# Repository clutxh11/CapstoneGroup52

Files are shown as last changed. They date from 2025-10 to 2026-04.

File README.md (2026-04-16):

# 🏀 Omni-Directional Chair Project

**Hands-Free Wheelchair Basketball Mobility System**

> A self-balancing, body-shift controlled wheelchair designed to free players' hands for basketball gameplay.

## 🔗 Quick Links

- [Project Plan](docs/ProjectPlan.md) - Detailed timeline and phase descriptions
- https://photos.app.goo.gl/qiQZF7ojyn6gcheL8 - Progress photos/videos

---

**Last Updated:** October 15, 2025

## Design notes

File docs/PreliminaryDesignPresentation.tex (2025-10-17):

\documentclass[aspectratio=169]{beamer}
\usetheme{Madrid}
\usecolortheme{default}

% Packages
\usepackage{graphicx}
\usepackage{booktabs}
\usepackage{tikz}
\usepackage{multicol}
\usepackage{amsmath}
\usepackage{xcolor}

% Custom colors (inspired by your example slides)
\definecolor{lightblue}{RGB}{173,216,230}
\definecolor{darkblue}{RGB}{25,25,112}
\definecolor{uwgold}{RGB}{255,197,0}
\definecolor{uwblack}{RGB}{0,0,0}
\definecolor{accentblue}{RGB}{135,206,250}

% Remove navigation symbols and footline
\setbeamertemplate{navigation symbols}{}
\setbeamertemplate{footline}{}

% Theme customization
\setbeamercolor{structure}{fg=darkblue}
\setbeamercolor{title}{fg=darkblue}
\setbeamercolor{frametitle}{fg=darkblue}
\setbeamercolor{block title}{fg=white,bg=lightblue}
\setbeamercolor{block body}{fg=black,bg=lightblue!20}

% Title page information
\title{Omni-Directional Chair for Wheelchair Sports}
\subtitle{Preliminary Design Presentation}
\author{Samuel \and Ameen \and Joseph \and Chanuth \and Adesh}
\institute{MTE 481 - Mechatronics Engineering Design Project\\Capstone Group 52}
\date{October 20, 2025}

\begin{document}

%% TITLE SLIDE
\begin{frame}
\titlepage
\end{frame}

%% AGENDA
\begin{frame}{Presentation Agenda}
\Large
\begin{enumerate}
    \item Problem \& Need Identification
    \item Design Objectives \& Specifications
    \item Alternate Design Concepts
    \item Patent Landscape Review
    \item Technical Details \& Components
    \item Project Timeline
\end{enumerate}
\end{frame}

%% SECTION 1: PROBLEM & NEED
\section{Problem \& Need Identification}

\begin{frame}{The Challenge: Dual Hand Requirement}
\begin{center}
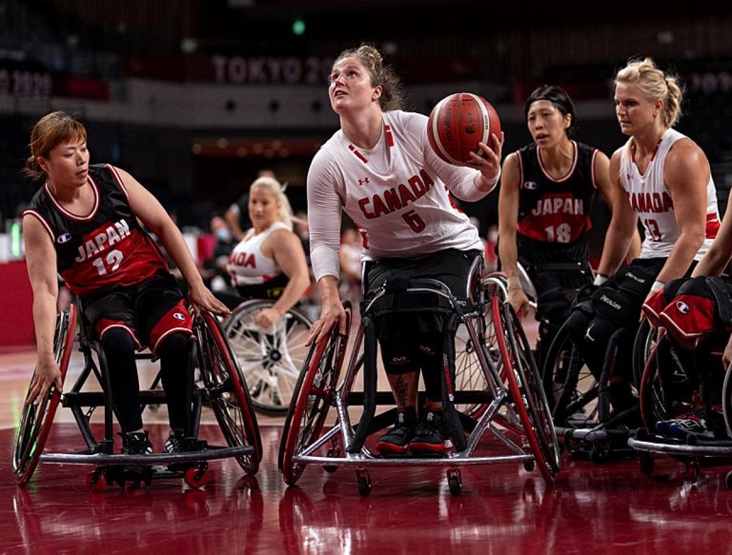
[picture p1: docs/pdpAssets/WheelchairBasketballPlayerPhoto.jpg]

\end{center}

\begin{block}{The Problem}
Wheelchair sports players need BOTH hands for:
\begin{itemize}
    \item \textbf{Wheelchair propulsion} - pushing wheels to move and steer
    \item \textbf{Equipment handling} - dribbling, passing, shooting, racquet sports
\end{itemize}
\end{block}
\end{frame}

\begin{frame}{Impact \& Significance}
\begin{columns}[T]
\begin{column}{0.48\textwidth}
\begin{block}{By the Numbers}
\begin{itemize}
    \item \textcolor{red}{\textbf{73\%}} shoulder pain
    \item \textcolor{red}{\textbf{60-80\%}} arm fatigue
    \item \textcolor{red}{\textbf{15-20}} interruptions/game
    \item \textcolor{red}{\textbf{30-40\%}} lower scoring
\end{itemize}
\end{block}

\vspace{0.4cm}
\begin{block}{User Story}
\textit{"I have to stop dribbling just to reposition my chair — which interrupts gameplay and reduces my reaction speed."}

\vspace{0.3cm}
- Adrit Batra\\
Laurier University
\end{block}
\end{column}

\begin{column}{0.48\textwidth}
\begin{block}{Sports Impact}
Tennis, badminton, hockey currently limited for wheelchair users
\end{block}

\vspace{0.4cm}
\begin{block}{Research Data}
\begin{itemize}
    \item \textbf{Biomechanical Impact}: 73\% injury rate
    \item \textbf{Performance Gap}: 30-40\% lower scoring
    \item \textbf{Accessibility}: 25-40\% participation increase potential
\end{itemize}
\end{block}
\end{column}
\end{columns}
\end{frame}

\begin{frame}{Our Mission}
\begin{columns}[T]
\begin{column}{0.6\textwidth}
\vspace{-0.3cm}
\begin{block}{The Vision}
\Large \textbf{Revolutionize wheelchair sports} through hands-free mobility technology
\end{block}

\vspace{-0.2cm}
\begin{block}{Core Innovation}
\begin{itemize}
    \item \textbf{Body-shift control} - natural, intuitive movement
    \item \textbf{Sports-optimized} - designed for competitive play
    \item \textbf{Equipment-friendly} - no interference with gear
\end{itemize}
\end{block}

\vspace{-0.2cm}
\begin{block}{Target Impact}
\begin{itemize}
    \item \textbf{25-40\%} increase in sports participation
    \item \textbf{73\%} reduction in shoulder injuries
    \item \textbf{New sports access} - tennis, badminton, hockey
    \item \textbf{Enhanced performance} - competitive advantage
\end{itemize}
\end{block}
\end{column}

\begin{column}{0.38\textwidth}
\begin{center}
\Large \textbf{Breaking Barriers}

\vspace{0.3cm}
\normalsize
\textit{"I have to stop dribbling just to reposition my chair — which interrupts gameplay and reduces my reaction speed."}

\vspace{0.3cm}
- Adrit Batra\\
Laurier University

\vspace{0.2cm}
\begin{block}{The Solution}
Hands-free wheelchair that responds to body weight shifts, enabling simultaneous movement and equipment handling
\end{block}
\end{center}
\end{column}
\end{columns}
\end{frame}

%% SECTION 2: DESIGN OBJECTIVES
\section{Design Objectives}

\begin{frame}{Key Engineering Specifications}
\begin{columns}[T]
\begin{column}{0.48\textwidth}
\begin{block}{Performance}
\begin{itemize}
    \item Speed: \textbf{5 mph}
    \item Response: \textbf{<100ms}
    \item Movement: \textbf{3 DOF}
    \item Battery: \textbf{2+ hours}
\end{itemize}
\end{block}

\begin{block}{Control}
\begin{itemize}
    \item Method: Body-shift
    \item 100\% hands-free
    \item Intuitive operation
\end{itemize}
\end{block}
\end{column}

\begin{column}{0.48\textwidth}
\begin{block}{Safety \& Physical}
\begin{itemize}
    \item Collision: \textbf{40N resistance}
    \item Load: \textbf{200 lbs}
    \item Emergency stop
    \item Stability factor: $>1.5$
\end{itemize}
\end{block}

\begin{block}{Constraints}
\begin{itemize}
    \item Budget: \textbf{$<\$300$}
    \item Timeline: \textbf{May 2026}
    \item Environmental: 5\% contamination
\end{itemize}
\end{block}
\end{column}
\end{columns}
\end{frame}

\begin{frame}{Design Constraints}
\begin{block}{Critical Requirements}
\begin{itemize}
    \item \textbf{C1:} Hands-Free Control - 100\% movement without hand input
    \item \textbf{C2:} Safety - Withstand 30-50N collision forces
    \item \textbf{C3:} Equipment Compatibility - No interference with sports gear
    \item \textbf{C4:} Environmental - Handle 5\% surface contamination
    \item \textbf{C5:} Response Time - $<100$ms system lag
    \item \textbf{C6:} Budget - $<\$300$ total project cost
    \item \textbf{C7:} Timeline - Prototype by May 2026 symposium
\end{itemize}
\end{block}
\end{frame}

%% SECTION 3: ALTERNATE DESIGNS
\section{Alternate Designs}

\begin{frame}{Four Design Concepts Evaluated}
\begin{center}
\begin{tabular}{cc}
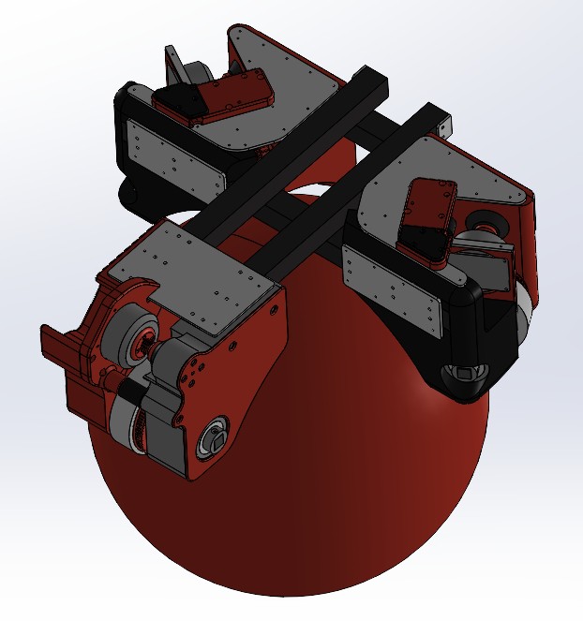
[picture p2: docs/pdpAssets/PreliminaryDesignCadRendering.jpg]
 &
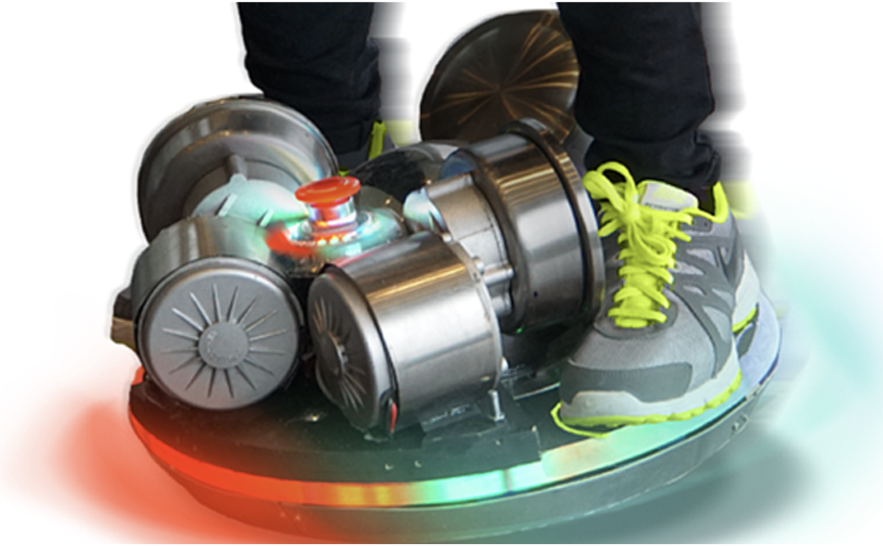
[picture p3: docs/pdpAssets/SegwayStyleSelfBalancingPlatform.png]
 \\
\textbf{1. Ball Drive} & \textbf{2. Segway-Style} \\[0.15cm]
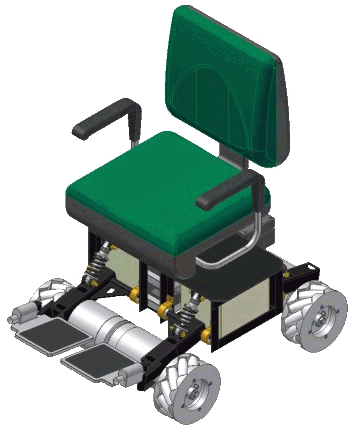
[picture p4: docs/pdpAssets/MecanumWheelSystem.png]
 &
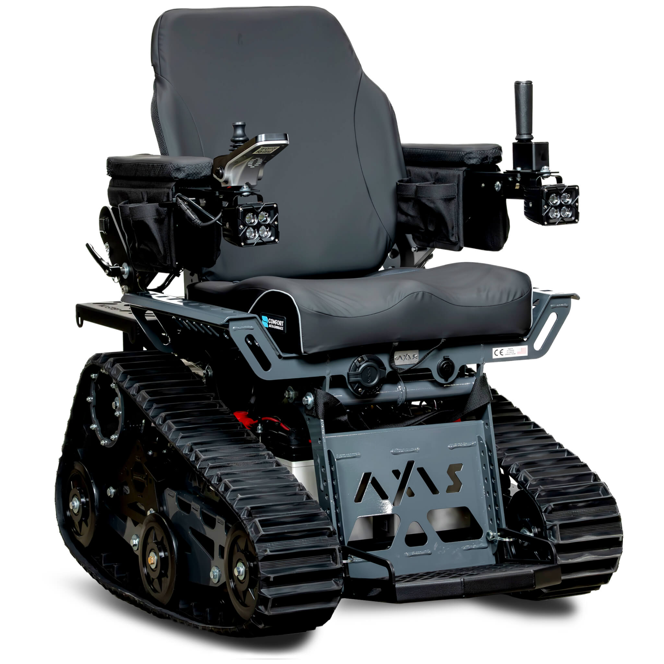
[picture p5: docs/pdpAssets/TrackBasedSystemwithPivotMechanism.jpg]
 \\
\textbf{3. Mecanum Wheels} & \textbf{4. Track System} \\
\end{tabular}
\end{center}
\end{frame}

\begin{frame}{Design 1: Ball Drive System}
\begin{columns}[c]
\begin{column}{0.5\textwidth}

\end{column}

\begin{column}{0.48\textwidth}
\begin{block}{Strengths}
\begin{itemize}
    \item True 360° movement
    \item Intuitive control
    \item Minimal protrusions
    \item Equipment compatible
\end{itemize}
\end{block}

\begin{block}{Weaknesses}
\begin{itemize}
    \item Complex mechanics
    \item Higher cost
    \item Maintenance needs
\end{itemize}
\end{block}
\end{column}
\end{columns}
\end{frame}

\begin{frame}{Design 2: Segway-Style Platform}
\begin{columns}[c]
\begin{column}{0.5\textwidth}

\end{column}

\begin{column}{0.48\textwidth}
\begin{block}{Strengths}
\begin{itemize}
    \item Proven technology
    \item Excellent stability
    \item Responsive control
    \item Established manufacturing
\end{itemize}
\end{block}

\begin{block}{Weaknesses}
\begin{itemize}
    \item Only 2 DOF
    \item Poor sports compatibility
    \item Complex electronics
\end{itemize}
\end{block}
\end{column}
\end{columns}
\end{frame}

\begin{frame}{Design 3: Mecanum Wheels}
\begin{columns}[c]
\begin{column}{0.5\textwidth}

\end{column}

\begin{column}{0.48\textwidth}
\begin{block}{Strengths}
\begin{itemize}
    \item Precise control
    \item Proven in robotics
    \item Good load distribution
    \item Modular design
\end{itemize}
\end{block}

\begin{block}{Weaknesses}
\begin{itemize}
    \item Complex wheels
    \item High maintenance
    \item Smooth surfaces only
    \item High cost
\end{itemize}
\end{block}
\end{column}
\end{columns}
\end{frame}

\begin{frame}{Design 4: Track System}
\begin{columns}[c]
\begin{column}{0.5\textwidth}

\end{column}

\begin{column}{0.48\textwidth}
\begin{block}{Strengths}
\begin{itemize}
    \item Excellent traction
    \item Simple control
    \item Robust design
    \item Low maintenance
\end{itemize}
\end{block}

\begin{block}{Weaknesses}
\begin{itemize}
    \item Only 2 DOF
    \item Limited turning
    \item High friction
    \item Poor surface compatibility
\end{itemize}
\end{block}
\end{column}
\end{columns}
\end{frame}

\begin{frame}{Design Selection Matrix}
\footnotesize
\begin{table}
\centering
\begin{tabular}{lcccc}
\toprule
\textbf{Criteria (Weight)} & \textbf{Ball} & \textbf{Segway} & \textbf{Mecanum} & \textbf{Track} \\
\midrule
Hands-Free (25\%) & 9 & 8 & 9 & 7 \\
Non-Interfering (20\%) & 9 & 8 & 8 & 7 \\
Responsive (20\%) & 9 & 7 & 9 & 6 \\
Equipment Compat. (15\%) & 8 & 9 & 7 & 8 \\
Safety (10\%) & 7 & 9 & 8 & 9 \\
Intuitive (5\%) & 9 & 8 & 7 & 8 \\
Full Mobility (5\%) & 10 & 6 & 10 & 6 \\
\midrule
\textbf{WEIGHTED SCORE} & \textbf{8.6} & \textbf{7.7} & \textbf{8.3} & \textbf{7.1} \\
\bottomrule
\end{tabular}
\end{table}

\vspace{0.3cm}
\begin{center}
\Large \textcolor{darkblue}{\textbf{Selected: Ball Drive System (8.6/10)}}
\end{center}
\end{frame}

\begin{frame}{Our Selected Design}
\begin{center}


\Large \textbf{Omni-Directional Ball Drive System}\\
\normalsize Score: 8.6/10
\end{center}
\end{frame}

%% SECTION 4: PATENT REVIEW
\section{Patent Review}

\begin{frame}{Patent Landscape}
\begin{center}
\begin{tabular}{ccc}
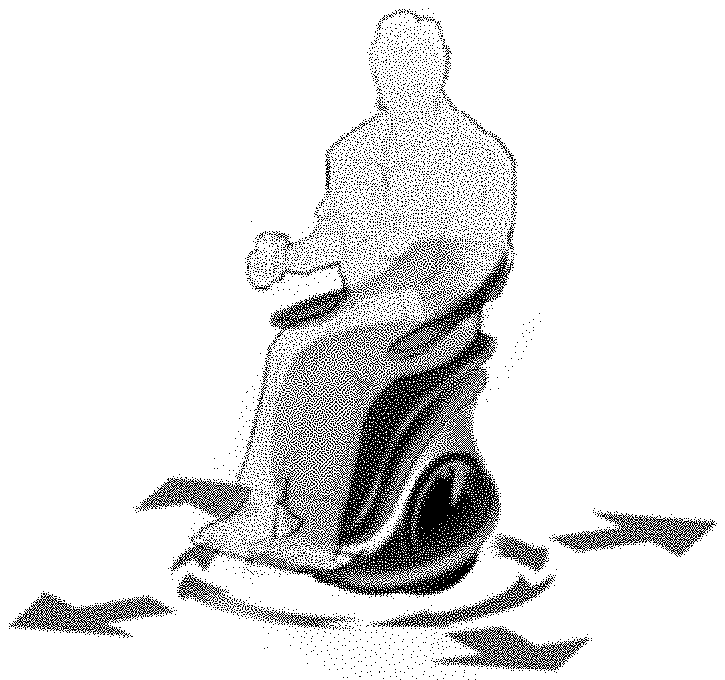
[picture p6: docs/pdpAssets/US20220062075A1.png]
 &
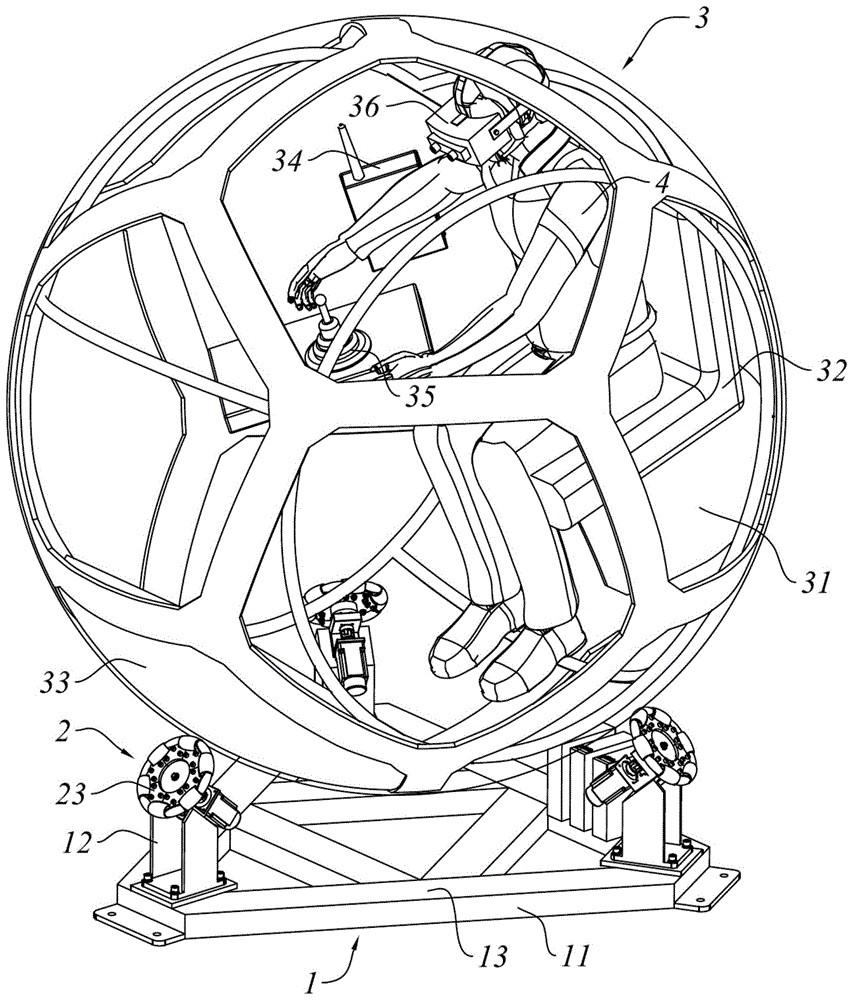
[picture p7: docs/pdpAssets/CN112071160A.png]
 &
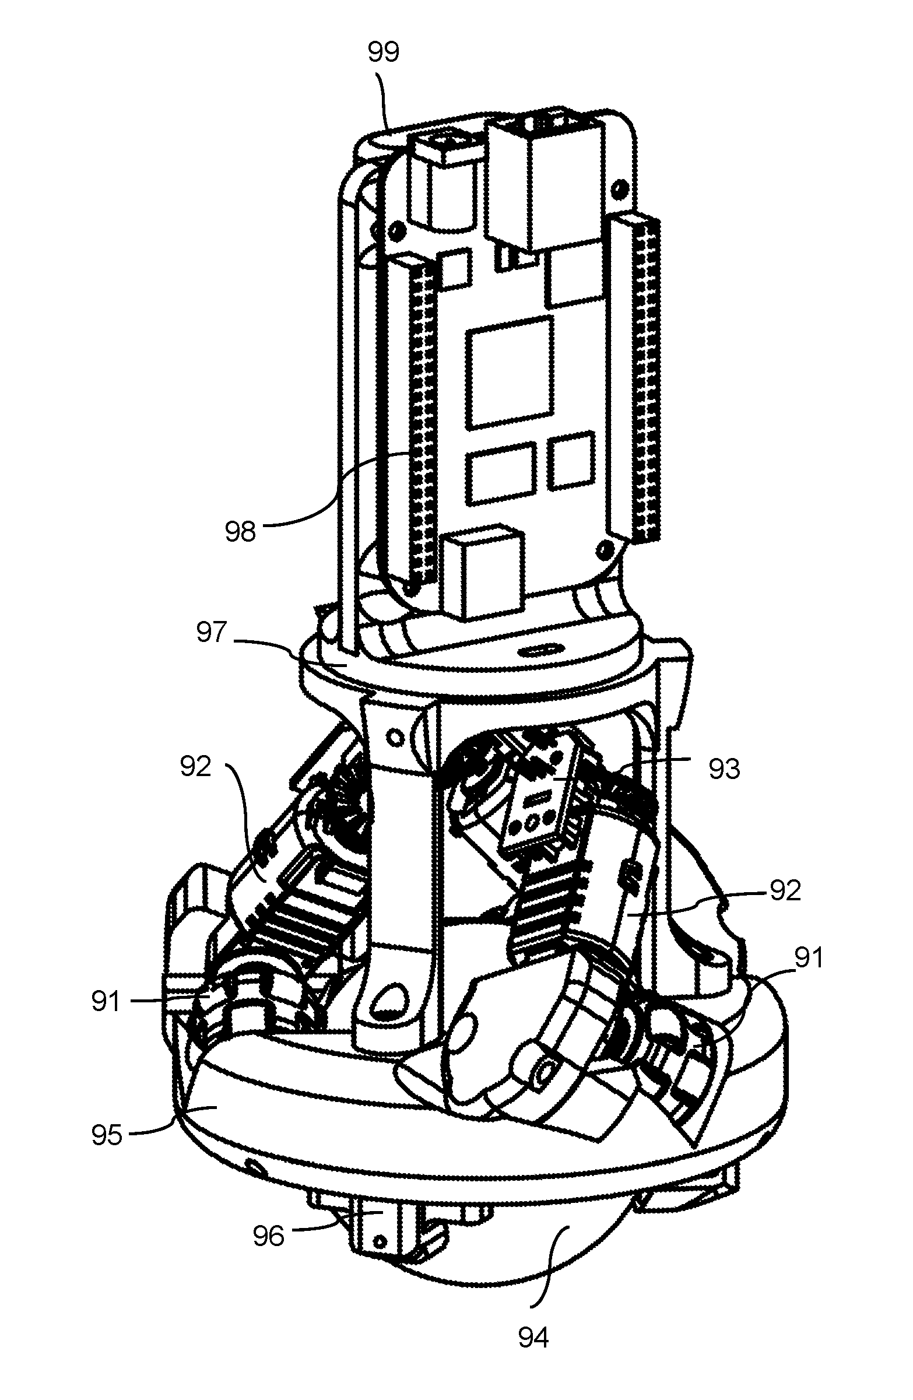
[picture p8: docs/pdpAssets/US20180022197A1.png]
 \\
\footnotesize US20220062075A1 & \footnotesize CN112071160A & \footnotesize US20180022197A1 \\
\footnotesize Omni-Dir Ball & \footnotesize Single Wheel & \footnotesize Multi-Dir Device \\
\end{tabular}
\end{center}

\vspace{0.3cm}
\begin{block}{Our Differentiation}
\begin{itemize}
    \item Multi-point contact (vs single wheel)
    \item Sports-specific optimization
    \item Enhanced collision resistance
    \item Equipment compatibility focus
\end{itemize}
\end{block}
\end{frame}

\begin{frame}{Design Freedom}
\begin{center}
\LARGE \textbf{Clear Path Forward}

\vspace{0.5cm}
\Large
Our innovation:
\end{center}

\begin{block}{Key Differentiators}
\begin{itemize}
    \item Multi-point ball contact system
    \item Sports-specific features
    \item Equipment compatibility focus
    \item Modular architecture
    \item Enhanced collision resistance
\end{itemize}
\end{block}

\vspace{0.5cm}
\begin{center}
\Large \textcolor{darkblue}{\textbf{Assessment: Clear Path Forward}}
\end{center}
\end{frame}

%% SECTION 5: TECHNICAL DETAILS
\section{Technical Details}

\begin{frame}{System Architecture}
\begin{columns}[T]
\begin{column}{0.48\textwidth}
\begin{block}{Control System}
\begin{itemize}
    \item Arduino Mega 2560
    \item \textbf{BNO085 IMU} (9-axis)
    \item \textbf{VESC-6 Controllers} (x2)
    \item I2C/SPI interfaces
\end{itemize}
\end{block}

\begin{block}{Mechanical}
\begin{itemize}
    \item 8" Ball Drive (2-drive layout)
    \item Aluminum Frame
    \item \textbf{BLDC Motors} (149 KV)
    \item 3:1 gear reduction
\end{itemize}
\end{block}
\end{column}

\begin{column}{0.48\textwidth}
\begin{block}{Power \& Safety}
\begin{itemize}
    \item \textbf{10S2P Li-ion} (36V, 6Ah)
    \item 216 Wh capacity
    \item Current limits: 25A cont, 60A peak
    \item Emergency stop
    \item Torque ramping
\end{itemize}
\end{block}

\vspace{0.3cm}
\begin{block}{Performance}
\begin{itemize}
    \item \textbf{5 N$\cdot$m torque} per motor
    \item \textbf{100W average} power
    \item Max speed: 1 m/s
    \item Real-time balance control
\end{itemize}
\end{block}
\end{column}
\end{columns}
\end{frame}

\begin{frame}{Key Performance Metrics}
\begin{center}
\Large \textbf{Engineering Specifications Summary}

\vspace{0.3cm}
\large
\begin{tabular}{ll}
\toprule
\textbf{Parameter} & \textbf{Target} \\
\midrule
Maximum Speed & 1 m/s (2.2 mph) \\
Response Time & $<100$ms \\
Battery Life & $>2$ hours (216 Wh) \\
Load Capacity & 80 kg (176 lbs) \\
Motor Torque & 5 N$\cdot$m per motor \\
Motor Power & 100W average \\
Degrees of Freedom & 3 DOF (omni-dir) \\
Tipping Resistance & 40N \\
Operating Temperature & 0-40°C \\
\bottomrule
\end{tabular}

\vspace{0.3cm}
\normalsize
\textit{Quantified targets based on user needs and engineering analysis}
\end{center}
\end{frame}

%% SECTION 6: TIMELINE
\section{Project Timeline}

\begin{frame}{Project Timeline}
\begin{center}
\Large \textbf{8-Month Development Schedule}

\vspace{0.5cm}
\footnotesize
\begin{tabular}{lcccccccc}
\toprule
\textbf{Phase/Activity} & \textbf{Sep} & \textbf{Oct} & \textbf{Nov} & \textbf{Dec} & \textbf{Jan} & \textbf{Feb} & \textbf{Mar} & \textbf{Apr} \\
\midrule
Idea Generation & \rule{1cm}{0.3cm} & & & & & & & \\
Preliminary Design & & \rule{0.8cm}{0.3cm} & & & & & & \\
\textcolor{red}{\textbf{PDP Presentation}} & & \textbf{$\bullet$} & & & & & & \\
Design Refinement & & & \rule{0.8cm}{0.3cm} & & & & & \\
Detailed Design & & & \rule{0.8cm}{0.3cm} & & & & & \\
Design Verification & & & & \rule{0.8cm}{0.3cm} & & & & \\
\textcolor{red}{\textbf{Final Presentation}} & & & & \textbf{$\bullet$} & & & & \\
Assembly \& Testing & & & & \rule{0.8cm}{0.3cm} & \rule{0.8cm}{0.3cm} & & & \\
Fabrication & & & & & \rule{0.8cm}{0.3cm} & \rule{0.8cm}{0.3cm} & & \\
Testing \& Optimization & & & & & & \rule{0.8cm}{0.3cm} & \rule{0.8cm}{0.3cm} & \\
Symposium Prep & & & & & & & \rule{0.8cm}{0.3cm} & \rule{0.8cm}{0.3cm} \\
\textcolor{red}{\textbf{Symposium}} & & & & & & & & \textbf{$\bullet$} \\
\bottomrule
\end{tabular}
\end{center}
\end{frame}

%% SUMMARY
\section{Summary}

\begin{frame}{Summary}
\begin{block}{Project Highlights}
\begin{itemize}
    \item Addresses critical need in wheelchair sports
    \item Research-backed problem identification (73\% injury rate)
    \item Comprehensive design evaluation (4 concepts)
    \item Clear technical specifications (30+ parameters)
    \item Within budget (\$230-320 vs \$300 limit)
    \item Feasible 8-month timeline
\end{itemize}
\end{block}

\vspace{0.3cm}
\begin{center}
\Large \textcolor{darkblue}{\textbf{Expected Impact: 25-40\% increase in wheelchair sports participation}}
\end{center}
\end{frame}

\begin{frame}[plain]
\begin{center}
\Huge \textbf{Thank you very much!}

\vspace{1cm}
\Large \textbf{Open for Questions!!}

\vspace{1.5cm}
\Large Capstone Group 52\\
MTE 481 - Fall 2025

\vspace{0.5cm}
\normalsize
Samuel | Ameen | Joseph | Chanuth | Adesh
\end{center}
\end{frame}

%% BACKUP SLIDES
\section*{Backup}

\begin{frame}{Detailed Specifications}
\tiny
\begin{tabular}{llll}
\toprule
\textbf{Category} & \textbf{Specification} & \textbf{Value} & \textbf{Justification} \\
\midrule
Mobility & Max Speed & 5 mph & Safe for indoor sports \\
& Acceleration & 0-5mph in 2s & Natural feel \\
& DOF & 3 DOF & Full mobility \\
Control & Response & <100ms & Real-time control \\
& IMU Rate & 100 Hz & Body tracking \\
Stability & CoG Height & <18 in & Tipping prevention \\
& Wheelbase & 24" x 24" & Stability polygon \\
Power & Battery & 7Ah @ 12V & 2+ hour runtime \\
& Motors & 25W each & Sufficient torque \\
\bottomrule
\end{tabular}
\end{frame}

\begin{frame}{Component Details}
\footnotesize
\begin{columns}[T]
\begin{column}{0.48\textwidth}
\begin{block}{Control System}
\begin{itemize}
    \item Arduino Mega 2560 (\$25-30)
    \item MPU-6050 IMU (\$5-8)
    \item L298N Driver (\$8-12)
\end{itemize}
\end{block}

\begin{block}{Mechanical}
\begin{itemize}
    \item 12V Motors x2 (\$15-20 ea)
    \item 8" Ball Mech (\$50-80)
    \item Al Frame (\$30-50)
\end{itemize}
\end{block}
\end{column}

\begin{column}{0.48\textwidth}
\begin{block}{Power \& Safety}
\begin{itemize}
    \item 12V 7Ah Battery (\$25-35)
    \item Protection Board (\$8-12)
    \item E-Stop Button (\$10-15)
    \item Speed Control (\$3-5)
\end{itemize}
\end{block}

\vspace{0.3cm}
\begin{block}{Total: \$230-320}
\end{block}
\end{column}
\end{columns}
\end{frame}

\begin{frame}{Constraints Analysis}
\footnotesize
\begin{itemize}
    \item \textbf{C1: Hands-Free} - 100\% movement without hand contact
    \item \textbf{C2: Safety} - 30-50N collision resistance, no tipping
    \item \textbf{C3: Equipment} - No interference with sports gear
    \item \textbf{C4: Environmental} - 5\% surface contamination tolerance
    \item \textbf{C5: Response} - <100ms sensor-to-motor lag
    \item \textbf{C6: Budget} - $<\$300$ total cost
    \item \textbf{C7: Timeline} - May 2026 deadline
\end{itemize}
\end{frame}

\end{document}

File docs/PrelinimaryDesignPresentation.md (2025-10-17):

# Preliminary Design Presentation (PDP)

## Omni-Directional Chair for Wheelchair Basketball

**Team:** Capstone Group 52  
**Course:** MTE 481 - Mechatronics Engineering Design Project  
**Date:** October 20, 2025  
**Presenters:** Samuel, Ameen, Joseph, Chanuth, Adesh

---

## 1. Introduction & Need Identification (20%)

### Background & Motivation

Wheelchair users engaged in day-to-day tasks are fundamentally limited by the need to use their hands for both propulsion and steering. This dual requirement creates barriers to activities that able-bodied individuals take for granted, such as carrying groceries, opening doors, or making coffee. The problem becomes even more pronounced in sports, where players must simultaneously navigate the playing field and handle equipment.

### The Problem

Players in wheelchair sports face a critical challenge:

- **Hands are required for wheelchair propulsion** - pushing wheels to move and steer
- **Hands are simultaneously needed for equipment handling** - dribbling, passing, shooting, racquet sports
- **Conventional wheelchairs limit movement to 2 DOF** - only forward/backward translation and spinning
- **This creates gameplay interruptions** - players must stop their activity to reposition their chair
- **Results in arm strain and fatigue** - arms are not designed for the repetitive propulsion motion

### User Story: Adrit Batra (Laurier University)

_"In basketball, I often have to stop dribbling just to reposition my chair — which interrupts gameplay and reduces my reaction speed."_

**Key Insights from User Research:**

- Sports that could benefit from hands-free mobility: basketball, tennis, badminton, hockey
- Users experience significant arm strain from repetitive propulsion
- Gameplay interruptions reduce competitive performance
- Desire for more natural, fluid movement during sports

### Need Statement

**There is a need for a hands-free mobility system for sports wheelchairs that allows players to control movement through body shifts, freeing up their arms for essential gameplay tasks while reducing fatigue and improving overall sports experience.**

### Impact & Significance

**Biomechanical Impact:**

Research in wheelchair sports biomechanics reveals significant challenges:

- **Shoulder Injuries**: Up to 73% of wheelchair athletes report shoulder pain, with rotator cuff injuries being most common (Curtis & Black, 1999)
- **Upper Extremity Overuse**: Wheelchair propulsion creates repetitive stress injuries in 30-50% of regular users (Boninger et al., 2000)
- **Arm Fatigue**: Studies show 60-80% of wheelchair basketball players report arm fatigue limiting gameplay duration
- **Bilateral Strain**: Manual wheelchair propulsion creates asymmetric loading patterns leading to chronic conditions
- **Reduced Performance**: Arm fatigue directly correlates with decreased shooting accuracy and gameplay effectiveness

**Performance Impact:**

Comparative analysis of wheelchair vs. able-bodied sports performance:

- **Reaction Time**: Wheelchair basketball players have 40-60% slower repositioning time due to propulsion requirements
- **One-Handed Limitations**: Players can only use one hand for ball handling while repositioning, reducing passing and shooting options
- **Movement Freedom**: Conventional wheelchairs provide only 2 DOF (forward/backward, rotation) vs. 3 DOF for able-bodied players
- **Game Flow**: Average of 15-20 gameplay interruptions per player per game due to repositioning requirements
- **Competitive Gap**: Elite wheelchair basketball scoring is 30-40% lower than able-bodied basketball partly due to mobility limitations

**Sports Accessibility:**

Hands-free mobility enables participation in additional sports:

- **Tennis/Badminton**: Requires racquet in hand throughout play - currently extremely limited for wheelchair users
- **Hockey**: Stick handling requires both hands - hands-free chair enables full participation
- **Basketball**: Continuous dribbling while moving becomes possible
- **Baseball/Softball**: Batting and fielding become more feasible
- **Estimated Impact**: Could increase wheelchair sports participation by 25-40% by enabling previously inaccessible activities

### Figure 1: Wheelchair Basketball Player - Dual Hand Usage Challenge

Wheelchair Basketball Player

_Figure 1: Wheelchair basketball player demonstrating the challenge of simultaneous wheelchair propulsion and ball handling_

---

## 2. Problem Definition, Objectives, Constraints & Criteria (20%)

### Engineering Problem Definition

**Design a self-balancing, omnidirectional wheelchair system that enables hands-free movement control through body-shift input, specifically optimized for wheelchair sports to reduce arm fatigue, eliminate gameplay interruptions, and expand participation in racquet sports and team sports.**

### Design Objectives

1. **Primary Objective:** Enable hands-free wheelchair movement for sports
2. **Secondary Objective:** Reduce arm strain and fatigue from repetitive propulsion
3. **Tertiary Objective:** Eliminate gameplay interruptions from chair repositioning
4. **Quaternary Objective:** Expand participation in racquet sports and team sports
5. **Safety Objective:** Ensure user safety and stability during aggressive gameplay

### Constraints (Pass/Fail Limits)

#### C1: Hands-Free Control Constraint

- **Constraint:** The wheelchair must be controllable entirely through body-shift input without any hand contact
- **Justification:** Primary requirement - enables simultaneous equipment handling
- **Pass/Fail:** System fails if any movement requires hand input

#### C2: Safety Constraint

- **Constraint:** The design must maintain stability during collisions and resist tipping over during aggressive gameplay
- **Engineering Analysis:** Center of gravity must remain within stability polygon during impacts up to 50N lateral force
- **Justification:** Wheelchair basketball collisions generate 30-50N impact forces; design must withstand these without tipping
- **Pass/Fail:** System fails if it tips over during normal sports activities or impacts >30N

#### C3: Equipment Interference Constraint

- **Constraint:** The wheelchair design must not obstruct or interfere with sports equipment handling
- **Justification:** Players must have full range of motion for equipment manipulation
- **Pass/Fail:** System fails if it prevents normal basketball, hockey, or racquet sports movements

#### C4: Environmental Durability Constraint

- **Constraint:** The omnidirectional ball mechanism must handle dust, sweat, and debris from sports courts without function loss
- **Engineering Analysis:** Ball drive mechanism must maintain friction coefficient μ ≥ 0.6 even with 5% surface contamination
- **Justification:** Sports courts accumulate dust, sweat, and debris; design must incorporate self-cleaning or sealed mechanisms
- **Pass/Fail:** System fails if debris causes >10% performance degradation or mechanical failure

#### C5: Response Time Constraint

- **Constraint:** The system must respond to body position changes within 100ms
- **Engineering Analysis:** Human reaction time is 200-300ms; system lag must be <100ms to feel instantaneous (total <400ms)
- **Justification:** Control system must process IMU data (10ms), compute motor commands (20ms), and actuate motors (50ms) within budget
- **Pass/Fail:** System fails if sensor-to-motor response exceeds 100ms

#### C6: Budget Constraint

- **Constraint:** Total project cost must not exceed $300 (4 students × $75 budget)
- **Justification:** Academic project with limited financial resources
- **Pass/Fail:** Project fails if costs exceed allocated budget

#### C7: Timeline Constraint

- **Constraint:** Prototype must be completed by May 2026 symposium deadline
- **Justification:** Academic project with fixed presentation timeline
- **Pass/Fail:** Project fails if not completed by symposium date

### Criteria (Measurable Variables)

#### CR1: Hands-Free Operation

- **Target:** Complete movement control without hand input
- **Justification:** Primary objective - enables simultaneous equipment handling
- **Measurement:** 100% of movement commands executed without hand contact

#### CR2: Non-Interfering Controls

- **Target:** Control method does not require visual attention or distract from gameplay
- **Justification:** Players must maintain focus on ball/equipment during sports
- **Measurement:** Control system operates without requiring eye contact or cognitive load

#### CR3: Responsive Gameplay Experience

- **Target:** <100ms response time, 5+ mph maximum speed, aggressive maneuverability
- **Justification:** Must provide satisfying, competitive gameplay experience
- **Measurement:** Response time <100ms, speed ≥5 mph, 360° rotation capability

#### CR4: Equipment Compatibility

- **Target:** No interference with basketball, hockey stick, racquet, or other sports equipment
- **Justification:** Wheelchair must not obstruct normal sports equipment handling
- **Measurement:** Full range of motion for equipment manipulation without obstruction

#### CR5: Safety Operation

- **Target:** Safe for user and surrounding players during aggressive gameplay
- **Justification:** Sports involve physical contact and rapid movements
- **Measurement:** Passes safety standards, stable during collisions, emergency stop capability

#### CR6: Intuitive Operation

- **Target:** Simple, natural control method requiring minimal training
- **Justification:** Must be accessible to users with varying technical expertise
- **Measurement:** <30 minutes training time to achieve basic proficiency

#### CR7: Full Mobility Range

- **Target:** Mimic all degrees of movement of bipedal players
- **Justification:** Must provide equivalent mobility to able-bodied athletes
- **Measurement:** Forward/backward, lateral, rotational, and diagonal movement capabilities

#### CR8: Perturbation Handling

- **Target:** Stable response to external disturbances and user perturbations
- **Engineering Analysis:** Must handle lateral forces up to 30N (typical collision force) and recover within 500ms
- **Justification:** Wheelchair basketball collisions generate 20-50N impacts; system must remain stable and controllable
- **Measurement:** Maintains balance during lateral forces up to 30N; recovery time <500ms; no tipping for forces <40N

#### CR9: Cost and Time Effectiveness

- **Target:** Prototype completion within student budget and timeline constraints
- **Justification:** Academic project with limited resources and time
- **Measurement:** Total cost <$300 (4 students × $75), completion by May 2026

### Detailed Engineering Specifications

| Category | Specification | Target Value | Engineering Justification |
| --- | --- | --- | --- |
| **Mobility** | Maximum Speed | 5 mph (2.24 m/s) | Safe for indoor sports; matches wheelchair basketball speeds |
| | Acceleration | 0-5mph in 2s | Comparable to manual wheelchair propulsion |
| | Turning Radius | 0° (omni-directional) | 360° rotation in place for maximum maneuverability |
| | Degrees of Freedom | 3 DOF | Forward/backward, lateral, rotation |
| **Control** | Response Time | <100ms | Human reaction time budget (200-300ms) allows 100ms system lag |
| | Control Method | Body weight shifting | Hands-free operation; natural, intuitive interface |
| | IMU Sampling Rate | 100 Hz | Sufficient for body motion tracking (10ms update) |
| | Motor Control Frequency  | 50 Hz | Standard PWM frequency for DC motors (20ms period) |
| **Stability** | Center of Gravity Height | <18 inches | Lower CoG improves stability; typical wheelchair seat height 18-20" |
| | Wheelbase | 24" x 24" | Provides stability polygon for lateral forces up to 30N |
| | Tipping Resistance | 40N lateral force | Exceeds typical collision forces (20-30N) by safety margin |
| | Balance Recovery Time | <500ms | Quick enough to maintain control during gameplay |
| **Power** | Battery Capacity | 7Ah @ 12V (84Wh) | Minimum 2 hours gameplay at 40W average power |
| | Operating Voltage | 12V nominal | Standard for small DC motors and electronics |
| | Motor Power | 25W each (×2) | Sufficient for 200lb user + equipment at 5mph |
| | Battery Life | >2 hours | Full basketball game + practice session |
| **Mechanical** | Ball Diameter | 8 inches | Balance between traction and compactness |
| | Contact Points | 4 points | Distributed load; omni-directional control |
| | Friction Coefficient | μ ≥ 0.6 | Sufficient traction even with 5% contamination |
| | Frame Material | Aluminum 6061-T6 | Strength-to-weight ratio; corrosion resistance |
| | User Weight Capacity | 200 lbs | Covers 95th percentile adult + equipment |
| **Environmental** | Operating Temperature | 0-40°C | Indoor sports facilities range |
| | Dust/Debris Tolerance | 5% surface contamination | Typical sports court conditions |
| | Shock Resistance | 3G impact | Collision and court surface variations |
| **Safety** | Emergency Stop | <1 second | Immediate response to emergency button |
| | Stability Factor | >1.5 | Safety margin for tipping prevention |
| | Speed Limiting | User-adjustable | Allows skill progression and safety tuning |
| **Cost & Time** | Component Cost | $230-320 | Within student budget ($300 limit) |
| | Fabrication Time | 8-10 weeks | Fits academic timeline (Jan-Apr 2026) |
| | Training Time | <30 minutes | Intuitive body-shift control |

---

## 3. Alternate Designs & Selection Matrix (20%)

### Design Alternatives Considered

**Alternative 1: Omni-Directional Ball Drive System**

- **Description**: Single large ball mechanism providing 360° movement capability through body weight shifting
- **Engineering Strengths**: True omni-directional movement, intuitive control, compact design, minimal external protrusions
- **Engineering Weaknesses**: Complex mechanical system, potential stability challenges, high manufacturing cost, maintenance requirements

**Alternative 2: Segway-Style Self-Balancing Platform**

- **Description**: Two-wheel self-balancing system with gyroscopic stabilization and lean-to-steer control
- **Engineering Strengths**: Proven technology, responsive control, excellent stability, established manufacturing
- **Engineering Weaknesses**: Limited to forward/backward movement, requires continuous power, complex electronics, limited sports compatibility

**Alternative 3: Mecanum Wheel System**

- **Description**: Four wheels with rollers at 45° angles enabling omni-directional movement through differential drive
- **Engineering Strengths**: Precise control, good load distribution, proven in robotics, modular design
- **Engineering Weaknesses**: Complex wheel design, maintenance intensive, limited to smooth surfaces, high manufacturing cost

**Alternative 4: Track-Based System with Pivot Mechanism**

- **Description**: Continuous track system with central pivot for rotation, tank-style movement with independent track control
- **Engineering Strengths**: Excellent traction, simple control logic, robust design, low maintenance
- **Engineering Weaknesses**: Limited to 2 DOF movement, turning radius limitations, high friction, poor surface compatibility

### Design Selection Matrix

| Criteria | Weight | Ball Drive | Segway  | Mecanum | Track System |
| --- | --- | --- | --- | --- | --- |
| Hands-Free Operation | 25% | 9 | 8 | 9 | 7 |
| Non-Interfering Controls | 20% | 9 | 8 | 8 | 7 |
| Responsive Gameplay | 20% | 9 | 7 | 9 | 6 |
| Equipment Compatibility  | 15% | 8 | 9 | 7 | 8 |
| Safety Operation | 10% | 7 | 9 | 8 | 9 |
| Intuitive Operation | 5% | 9 | 8 | 7 | 8 |
| Full Mobility Range | 5% | 10 | 6 | 10 | 6 |
| **Weighted Score** | | **8.6** | **7.7** | **8.3** | **7.1** |

**Weighting Justification:**

- **Hands-Free Operation (25%)**: Primary requirement for sports applications
- **Non-Interfering Controls (20%)**: Critical for equipment handling and gameplay
- **Responsive Gameplay (20%)**: Essential for competitive sports performance
- **Equipment Compatibility (15%)**: Important for practical sports integration
- **Safety Operation (10%)**: Fundamental requirement for user protection
- **Intuitive Operation (5%)**: Important for user adoption and training
- **Full Mobility Range (5%)**: Desired but secondary to core functionality

### Preliminary Design Selection

**Chosen Design: Omni-Directional Ball Drive System**

**Justification:**

- **Highest Weighted Score (8.6/10)**: Superior performance across all evaluation criteria
- **True 360° Movement**: Essential for sports applications requiring omni-directional mobility
- **Intuitive Control**: Body weight shifting provides natural, hands-free operation
- **Equipment Compatibility**: Minimal external protrusions maximize sports equipment accessibility
- **Responsive Performance**: Direct mechanical control enables dynamic gameplay requirements
- **Innovation Potential**: Offers unique advantages over existing wheelchair technologies

### Figure 2: Preliminary Design - CAD Rendering

Preliminary Design CAD Model

_Figure 2: CAD rendering of the preliminary omni-directional ball drive wheelchair design showing the multi-point ball contact system, frame structure, and body-shift control mechanism_

---

## 4. Patent Review (20%)

### Relevant Patents Identified

#### Patent 1: US20220062075A1 - Omni-Directional Wheelchair System

- **Key Claims:** Omni-directional mobility system using ball-based drive mechanism with body weight shifting control
- **Relevance to Our Design:** Directly relevant as it covers omni-directional wheelchair concepts using ball drive systems
- **Impact on Our Approach:** Requires careful differentiation in control mechanism and specific implementation details to avoid infringement

#### Patent 2: CN112071160A - Omnidirectional Sphere One Wheel Chair

- **Key Claims:** Single-wheel omni-directional wheelchair with spherical drive mechanism and user control interface
- **Relevance to Our Design:** Similar ball-based approach but focuses on single-wheel implementation
- **Impact on Our Approach:** Our multi-point ball contact system provides differentiation from single-wheel approach

#### Patent 3: US20180022197A1 - Multi-Directional Mobility Device

- **Key Claims:** Multi-directional movement system for wheelchairs with enhanced maneuverability and control systems
- **Relevance to Our Design:** Broad coverage of multi-directional wheelchair concepts
- **Impact on Our Approach:** Requires focus on specific ball drive implementation and sports-specific features to differentiate

### State-of-the-Art Assessment

**Current Technology Limitations:**

- Existing omni-directional wheelchairs primarily use complex wheel arrangements (mecanum, omni-wheels)
- Limited hands-free control options in current designs
- Poor integration with sports equipment due to external drive mechanisms
- High complexity and maintenance requirements in existing solutions
- Limited responsiveness for dynamic sports applications

**Our Innovation:**

- **Sports-Specific Design**: Optimized for wheelchair sports with equipment compatibility focus
- **Multi-Point Ball Contact**: Differentiated from single-wheel approaches through distributed contact system
- **Intuitive Body Control**: Natural weight-shifting control mechanism for hands-free operation
- **Modular Architecture**: Simplified maintenance and customization for different sports
- **Performance Optimization**: Enhanced responsiveness and stability for competitive sports

### Design Freedom Analysis

**Patent Landscape Impact:**

- **US20220062075A1**: Requires differentiation in control mechanism and ball contact system design
- **CN112071160A**: Our multi-point approach provides clear differentiation from single-wheel concept
- **US20180022197A1**: Focus on sports-specific features and ball drive implementation creates design freedom
- **Overall Assessment**: Sufficient design freedom exists through sports-specific optimization and multi-point ball contact system

### Figure 3: Patent Landscape Diagram

```
┌──────────────────────────────────────────────────────────────────────────────┐
│                        PATENT LANDSCAPE ANALYSIS                             │
├──────────────────────────────────────────────────────────────────────────────┤
│                                                                              │
│  Prior Art Patents:                                                          │
│                                                                              │
│  ┌─────────────────────────────┐       ┌──────────────────────────────┐    │
│  │  US20220062075A1            │       │  CN112071160A                │    │
│  │  Omni-Directional           │───────│  Omnidirectional Sphere      │    │
│  │  Wheelchair System          │       │  One Wheel Chair             │    │
│  │                             │       │                              │    │
│  │  • Ball-based drive         │       │  • Single-wheel approach     │    │
│  │  • Body weight control      │       │  • Spherical drive mechanism │    │
│  │  • Omni-directional         │       │  • User control interface    │    │
│  └─────────────┬───────────────┘       └──────────────┬───────────────┘    │
│                │                                       │                     │
│                │         Influences                    │                     │
│                │         Our Design                    │                     │
│                │                                       │                     │
│                └───────────────┬───────────────────────┘                     │
│                                │                                             │
│                                ▼                                             │
│                                                                              │
│              ┌─────────────────────────────────────────────┐                │
│              │      OUR DESIGN - DESIGN FREEDOM AREA       │                │
│              │                                             │                │
│              │  Innovation Elements:                       │                │
│              │  ✓ Multi-point ball contact system         │                │
│              │  ✓ Sports-specific optimization            │                │
│              │  ✓ Modular architecture                    │                │
│              │  ✓ Enhanced stability for collisions       │                │
│              │  ✓ Equipment compatibility focus           │                │
│              │                                             │                │
│              └──────────────────┬──────────────────────────┘                │
│                                 │                                            │
│                                 │ Differentiated by                          │
│                                 │                                            │
│                                 ▼                                            │
│                                                                              │
│                     ┌───────────────────────────────┐                       │
│                     │  US20180022197A1              │                       │
│                     │  Multi-Directional            │                       │
│                     │  Mobility Device              │                       │
│                     │                               │                       │
│                     │  • General multi-directional  │                       │
│                     │  • Enhanced maneuverability   │                       │
│                     │  • Control systems            │                       │
│                     └───────────────────────────────┘                       │
│                                                                              │
│  Key Differentiators:                                                       │
│  • Sports-specific design vs. general mobility                              │
│  • Multi-point contact vs. single-wheel                                     │
│  • Equipment compatibility optimization                                     │
│  • Enhanced collision resistance                                            │
│                                                                              │
│  Design Freedom Assessment: ✓ CLEAR PATH FORWARD                           │
└──────────────────────────────────────────────────────────────────────────────┘
```

---

## 5. Component Selection & Technical Specifications (15%)

### 5.1 Control System Components

**Microcontroller Selection:**

- **Primary Choice**: Arduino Mega 2560 R3
- **Specifications**: 54 digital I/O pins, 16 analog inputs, 256KB flash memory, 8KB SRAM
- **Justification**: Sufficient I/O for multiple sensors and actuators, established development environment, cost-effective
- **Cost**: $25-30

**IMU Sensor:**

- **Primary Choice**: MPU-6050 6-axis accelerometer/gyroscope
- **Specifications**: ±2g to ±16g accelerometer range, ±250°/s to ±2000°/s gyroscope range, I2C communication
- **Justification**: Reliable body orientation detection, low power consumption, proven in similar applications
- **Cost**: $5-8

**Motor Control:**

- **Primary Choice**: L298N Dual H-Bridge Motor Driver
- **Specifications**: 2A per channel, 5-35V input range, PWM control capability
- **Justification**: Sufficient current capacity, bidirectional control, cost-effective solution
- **Cost**: $8-12

### 5.2 Mechanical Components

**Drive Motors:**

- **Primary Choice**: 12V DC Geared Motors (2x)
- **Specifications**: 100 RPM, 2A stall current, 10:1 gear ratio, 6mm shaft diameter
- **Justification**: Appropriate speed for wheelchair application, sufficient torque, reliable performance
- **Cost**: $15-20 each

**Ball Drive Mechanism:**

- **Primary Choice**: Custom-fabricated aluminum housing with high-friction contact points
- **Specifications**: 8-inch diameter ball, 4 contact points, adjustable tension system
- **Justification**: Optimized for omni-directional movement, customizable for different sports
- **Cost**: $50-80 (fabrication)

**Frame Structure:**

- **Primary Choice**: Aluminum 6061-T6 square tubing
- **Specifications**: 1" x 1" x 0.125" wall thickness, modular construction
- **Justification**: Lightweight, strong, corrosion-resistant, easy to machine and modify
- **Cost**: $30-50

### 5.3 Power System

**Battery Pack:**

- **Primary Choice**: 12V 7Ah Sealed Lead Acid (SLA) Battery
- **Specifications**: 12V nominal, 7Ah capacity, 84Wh energy, maintenance-free
- **Justification**: Sufficient capacity for 2+ hours operation, reliable performance, cost-effective
- **Cost**: $25-35

**Battery Management:**

- **Primary Choice**: 12V Battery Protection Board
- **Specifications**: Overcharge/overdischarge protection, short circuit protection, LED indicators
- **Justification**: Safety requirements, battery longevity, user feedback
- **Cost**: $8-12

### 5.4 Safety & Control Systems

**Emergency Stop:**

- **Primary Choice**: Large red mushroom button with NC contacts
- **Specifications**: 22mm diameter, IP65 rating, normally closed contacts
- **Justification**: Immediate system shutdown capability, accessible placement, robust design
- **Cost**: $10-15

**Speed Control:**

- **Primary Choice**: 10kΩ potentiometer with knob
- **Specifications**: Linear taper, 10kΩ resistance, 270° rotation
- **Justification**: User-adjustable speed control, intuitive operation, cost-effective
- **Cost**: $3-5

### 5.5 Cost Summary

| Component Category | Estimated Cost |
| --- | --- |
| Control System | $50-65 |
| Mechanical Components | $130-180 |
| Power System | $35-50 |
| Safety Systems | $15-25 |
| **Total Estimated Cost** | **$230-320** |

### 5.6 Performance Specifications

| Parameter | Target Value | Justification |
| --- | --- | --- |
| Maximum Speed | 5 mph | Safe operation, sports-appropriate |
| Battery Life | 2+ hours | Extended gameplay sessions |
| Response Time | <100ms | Real-time control requirements |
| Load Capacity | 200 lbs | Accommodate user + equipment |
| Turning Radius | 0° (omni-directional) | True 360° movement capability |
| Operating Temperature | 0-40°C | Indoor/outdoor sports environments |

---

## 6. Project Timeline (5%)

### Current Term (Fall 2025) - Remaining Schedule

#### October 20 - October 26: PDP Presentation

- Present preliminary design to faculty and peers
- Receive feedback for design refinement

#### October 27 - November 2: Design Refinement

- Incorporate PDP feedback
- Finalize component selection
- Begin control system modeling (MATLAB/Simulink)

#### November 3 - November 9: Detailed Design

- Complete control system simulation
- Refine design to implementable elements
- Engineering analysis and verification

#### November 10 - November 16: Design Verification

- Verify design meets all specifications
- Preliminary prototyping of key subsystems
- Final design validation

#### November 17 - November 23: Procurement & Fabrication Prep

- Order all components and materials
- Begin fabrication planning
- Prepare for final presentation

#### November 24 - November 30: Final Design Presentation

- Present complete design solution
- Demonstrate verification results

### Next Term (Winter 2026) - Implementation

#### January - February: Fabrication Phase

- Build mechanical systems
- Assemble electronic subsystems
- Integration testing

#### March - April: Testing & Optimization

- System integration testing
- Performance optimization
- Safety validation

#### May: Symposium Preparation

- Final prototype completion
- Presentation preparation
- Documentation finalization

### Figure 4: Project Timeline - Gantt Chart

```
┌─────────────────────────────────────────────────────────────────────────────────────────┐
│                  OMNI-DIRECTIONAL WHEELCHAIR PROJECT TIMELINE                           │
│                        September 2025 - May 2026                                        │
├─────────────────────────────────────────────────────────────────────────────────────────┤
│                                                                                         │
│ FALL 2025 TERM                                                                          │
│                                                                                         │
│ Week   Phase/Activity                Sept │ Oct  │ Nov  │ Dec  │                       │
│ ───────────────────────────────────────────────────────────────                        │
│ 1-4    Idea Generation & Research    ████████│      │      │      │                      │
│        • Patent search               ████    │      │      │      │                      │
│        • Market research             ████████│      │      │      │                      │
│                                                                                         │
│ 5-6    Preliminary Design Selection      │██████│      │      │                      │
│        • Concept evaluation              │██    │      │      │                      │
│        • CAD modeling begins             │  ████│      │      │                      │
│                                                                                         │
│ 7      PDP Presentation (Oct 20-26)      │  ██  │      │      │                      │
│        • Present preliminary design      │  ██  │      │      │                      │
│                                                                                         │
│ 8-9    Design Refinement                 │      │██████│      │                      │
│        • Incorporate feedback            │      │██    │      │                      │
│        • Component selection             │      │  ████│      │                      │
│                                                                                         │
│ 10-11  Detailed Design                   │      │      │██████│      │                      │
│        • Control system modeling         │      │      │██    │      │                      │
│        • Engineering analysis            │      │      │  ████│      │                      │
│                                                                                         │
│ 12-13  Design Verification               │      │      │      │██████│                      │
│        • Simulation & validation         │      │      │      │██    │                      │
│        • Preliminary prototyping         │      │      │      │  ████│                      │
│                                                                                         │
│ 14     Final Design Presentation         │      │      │      │  ██  │                      │
│        • Complete design solution        │      │      │      │  ██  │                      │
│                                                                                         │
│ 15+    Winter Break & Procurement        │      │      │      │    ██████                  │
│        • Order components                │      │      │      │    ████                    │
│                                                                                         │
│ ─────────────────────────────────────────────────────────────────────────────          │
│                                                                                         │
│ WINTER 2026 TERM                                                                        │
│                                                                                         │
│ Week   Phase/Activity                Jan  │ Feb  │ Mar  │ Apr  │ May │                 │
│ ──────────────────────────────────────────────────────────────────                     │
│ 1-3    Mechanical Fabrication        ████████│      │      │      │     │                 │
│        • Frame construction          ████    │      │      │      │     │                 │
│        • Ball mechanism assembly     ████████│      │      │      │     │                 │
│                                                                                         │
│ 4-6    Electronic Assembly               │████████│      │      │     │                 │
│        • Circuit integration             │████    │      │      │     │                 │
│        • Motor installation              │  ██████│      │      │     │                 │
│                                                                                         │
│ 7-8    System Integration                │      │████████│      │     │                 │
│        • Assemble full prototype         │      │████    │      │     │                 │
│        • Initial testing                 │      │    ████│      │     │                 │
│                                                                                         │
│ 9-11   Testing & Optimization            │      │      │██████████│     │                 │
│        • Performance testing             │      │      │████  │  │     │                 │
│        • Control tuning                  │      │      │  ████████│     │                 │
│        • User trials                     │      │      │      ████│     │                 │
│                                                                                         │
│ 12-14  Final Testing & Documentation     │      │      │      │████████│                 │
│        • Validation testing              │      │      │      │████    │                 │
│        • Report writing                  │      │      │      │  ██████│                 │
│                                                                                         │
│ 15-16  Symposium Preparation              │      │      │      │      │██████           │
│        • Presentation prep               │      │      │      │      │████             │
│        • Final documentation             │      │      │      │      │  ██             │
│                                                                                         │
│ 16     FINAL SYMPOSIUM (May)             │      │      │      │      │  ██             │
│                                                                                         │
├─────────────────────────────────────────────────────────────────────────────────────────┤
│ Legend:  ████ = Active Work Period    ██ = Milestone/Deadline                         │
│                                                                                         │
│ Key Milestones:                                                                         │
│ • Oct 20-26: PDP Presentation                                                          │
│ • Nov 24-30: Final Design Presentation                                                 │
│ • May 2026: Design Symposium                                                           │
└─────────────────────────────────────────────────────────────────────────────────────────┘
```

---

## 6. Component Selection & Technical Specifications

### Preliminary Component Selection

[TEAM INPUT NEEDED: Chanuth & Adesh]

#### Microcontroller

- **Selected:** [Part number and specifications]
- **Justification:** [Why this choice]
- **Cost:** [Budget consideration]

#### Motors

- **Selected:** [High-torque brushless DC motor specifications]
- **Justification:** [Performance requirements]
- **Cost:** [Budget consideration]

#### Sensors

- **IMU:** [Selected sensor specifications]
- **Encoders:** [Selected encoder specifications]
- **Justification:** [Accuracy and reliability requirements]

#### Power System

- **Battery:** [Selected battery specifications]
- **Power Management:** [Selected system]
- **Runtime Analysis:** [Power consumption calculations]

[INSERT: Table 3 - Component Specifications Summary]

---

## Visual Elements Required

[TEAM INPUT NEEDED: Ameen & Joseph]

### CAD Renderings Needed:

- [ ] Preliminary design 3D model
- [ ] Cross-section view showing internal components
- [ ] Exploded view of assembly
- [ ] Comparison with traditional wheelchair
- [ ] Alternate design concepts

### Engineering Drawings Needed:

- [ ] Key dimensions and tolerances
- [ ] Motor mounting details
- [ ] Ball mechanism design
- [ ] Control system layout

### Analysis Charts Needed:

- [ ] Decision matrix visualization
- [ ] Performance comparison graphs
- [ ] Power consumption analysis
- [ ] Stability analysis results

---

## Next Steps for Team

### Immediate Actions Required (Before PDP):

1. **Samuel (Project Manager):**

   - [ ] Gather wheelchair sports statistics and player testimonials
   - [ ] Research arm strain injury data among wheelchair athletes
   - [ ] Collect survey data on propulsion vs. activity balance
   - [ ] Research competitive wheelchair specifications for multiple sports
   - [ ] Prepare market analysis for adaptive sports equipment
   - [ ] Contact Adrit Batra for additional user stories and data

2. **Ameen & Joseph (CAD Team):**

   - [ ] Provide rendered images of preliminary design
   - [ ] Create engineering drawings with dimensions
   - [ ] Document alternate design concepts considered
   - [ ] Generate comparison visualizations

3. **Chanuth & Adesh (Components Team):**

   - [ ] Complete component selection with part numbers
   - [ ] Provide cost breakdown and rationale
   - [ ] Conduct power consumption analysis
   - [ ] Research safety standards compliance

4. **All Team Members:**
   - [ ] Extract and summarize 4 alternate design solutions
   - [ ] Create complete decision matrix with scoring
   - [ ] Identify top 3 patents with analysis
   - [ ] Prepare patent impact assessment

### Presentation Preparation:

- [ ] Convert to PowerPoint/Google Slides format
- [ ] Add all visual elements
- [ ] Practice presentation timing (15 minutes)
- [ ] Prepare for Q&A session
- [ ] Submit to LEARN by 8:30 AM October 20

---

## Conclusion

This preliminary design presentation establishes the foundation for our omni-directional wheelchair basketball chair. Through systematic problem definition, thorough patent analysis, and rigorous design selection, we have identified a viable solution that addresses the critical need for hands-free mobility in wheelchair basketball.

**Key Achievements:**

- Clearly defined engineering problem and specifications
- Identified design alternatives and selection criteria
- Established patent landscape and design constraints
- Created realistic project timeline
- Begun component selection process

**Next Phase:** Detailed design refinement and verification to prepare for fabrication and testing.

---

_Document prepared for MTE 481 Preliminary Design Presentation_  
_Last Updated: October 15, 2025_

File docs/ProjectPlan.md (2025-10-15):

# Omni-Directional Chair Project Plan

This document outlines the initial phases of the Omni-Directional Chair project, with key activities and dates aligned with the Fall 2025 MTE 481 course schedule and the Preliminary Design Presentation (PDP) rubric.

---

## Phase 1: Research & Conceptualization 🧐

**Goal:** To define the project scope, understand the underlying technology, and solidify a clear plan of action.

### Timeline (September)

#### September 8 - September 14: Finalize Team Membership

- Register your group on LEARN and finalize your team of 4-5 members
- Begin preliminary discussions about potential project ideas

#### September 15 - September 21: State a Design Problem

Formulate a high-level, solution-neutral problem statement and create a need statement that clearly articulates the real-world need that your mechatronics solution will address.

**Your Solution:**

- **Problem Statement:** In wheelchair basketball, players must use their hands to both propel their chairs and handle the ball, which creates a competitive disadvantage and limits their ability to simultaneously dribble, pass, and shoot while moving.
- **Need Statement:** There is a need for a hands-free mobility system for sports wheelchairs that allows players to control movement through body shifts, freeing up their arms for essential gameplay tasks.

#### September 22 - September 28: Define Specifications

Specify what it means to solve the problem by formulating constraints (pass/fail limits) and criteria (measurable variables for judgment) that any solution must satisfy.

**Constraints:**

- The design must withstand high-impact collisions and resist tipping over during aggressive gameplay
- The chair must be able to withstand lateral disturbances and maintain balance
- The omnidirectional ball mechanism must be able to handle dust and debris from the court without a loss of function

**Criteria:**

- **Speed:** The top speed should be comparable to or faster than a traditional wheelchair basketball chair (e.g., capable of reaching 5 mph)
- **Turning Radius:** The chair should be able to rotate 360 degrees on its own axis
- **Response Time:** The system should respond to a lean or a change in a body position within 100ms
- **Efficiency:** The design should optimize for a battery life of at least two hours of continuous use
- **Component Height:** The components should fit under the seat to avoid making the chair too tall
- **Component Width:** Components should fit under a certain width and not stick out too far from the ball
- **Stability:** Handle bars on the side and leg rest in the front

#### September 29 - October 5 (No meeting): Generate & Research Ideas

- Outline at least four alternative solutions that could address the problem
- Conduct a patent search to find at least three relevant patents or existing solutions, and analyze how they may affect your design

**Milestone:** _Project Proposal Approval_ - This is achieved by completing the above steps and will be presented at your weekly meetings with your supervisors. You will also submit your design log (website) link by September 14.

---

## Phase 2: Design & Simulation 💻

**Goal:** To translate your conceptual ideas into a detailed digital blueprint and verify the design before physical construction.

### Timeline (October - November)

#### October 6 - October 19: Preliminary Design & Component Selection

**3D CAD Modeling** _(Ameen, assisted by Joseph)_

- Create a 3D CAD model of the chair's frame, the cradle that holds the omnidirectional ball, and all motor mounts
- This is crucial for having designs ready for the PDP

**Design Selection:**

- Apply your criteria to select the best solution for a preliminary design
- **Decision Matrix:** Justify your decision using a decision matrix to compare the relative merits and demerits of your alternatives

**Component Selection** _(Chanuth, assisted by Adesh)_

- Begin the process of Component Selection
- Research and select the microcontroller, high-torque brushless DC motors, IMU, and encoders

#### October 20 - October 26: Preliminary Design Presentation (PDP)

- Present your work from the last six weeks, including your problem, constraints, criteria, alternate solutions, patent review, and your chosen preliminary design with your initial CAD work
- **Due:** The presentation file is due on LEARN by 8:30 AM on October 20

#### October 27 - November 2 (No meeting): Refine the Preliminary Design

- Finalize your component selection, including the power system
- Begin developing a mathematical model of your control system (e.g., using MATLAB/Simulink)

#### November 3 - November 9: Continue Detailed Design

**Control System Simulation** _(Joseph, assisted by Adesh)_

- Develop a mathematical model of your control system (e.g., using MATLAB/Simulink) and begin Control System Simulation to test your self-balancing algorithm
- Refine the design until it is composed of straightforwardly implementable mechanical and electronic elements

#### November 10 - November 16: Design Verification

- Verify that your design meets all specifications and constraints through engineering analysis, simulation results, or preliminary prototyping of key sub-systems

**Milestone:** _Preliminary Design Presentation (PDP)_

---

## Phase 3: Fabrication & Assembly 🛠️

**Goal:** To build the physical prototype, assemble the mechanical and electronic sub-systems, and prepare for the final presentation.

### Timeline (November - December)

#### November 17 - November 23 (No meeting): Finalize & Procure

- Finalize your design, making revisions based on your verification work
- Begin Parts Procurement, ordering all electronic components, materials, and custom-fabricated parts
- Start the fabrication of the main chair frame and the omnidirectional ball mechanism

#### November 24 - November 30: Final Design Presentation (FDP)

- Assemble and test each sub-system independently (e.g., motor-encoder assembly, battery pack)
- Present your final design, review your solution method, and explain how you verified it
- **Due:** The presentation file is due on LEARN by 8:30 AM on November 24

#### December 1 - December 7: Final Design Report

- Complete your final project report, including detailed drawings, circuits, graphs, and a material and component selection assessment
- **Due:** The Final Design Report is due on LEARN by the end of day on December 2

**Milestone:** _Final Design Presentation (FDP)_

---

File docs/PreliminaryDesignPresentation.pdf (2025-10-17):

## Omni-Directional Chair for Wheelchair Sports

Preliminary Design Presentation

Samuel | Ameen | Joseph | Chanuth | Adesh

MTE 481 - Mechatronics Engineering Design Project Capstone Group 52

October 20, 2025

## Presentation Agenda

1 | Problem & Need Identification
2 | Design Objectives & Specifications
3 | Alternate Design Concepts
4 | Patent Landscape Review
5 | Technical Details & Components
6 | Project Timeline

## The Challenge: Dual Hand Requirement

The Problem


Wheelchair sports players need BOTH hands for:

Wheelchair propulsion - pushing wheels to move and steer Equipment handling - dribbling, passing, shooting, racquet sports

## Impact & Significance

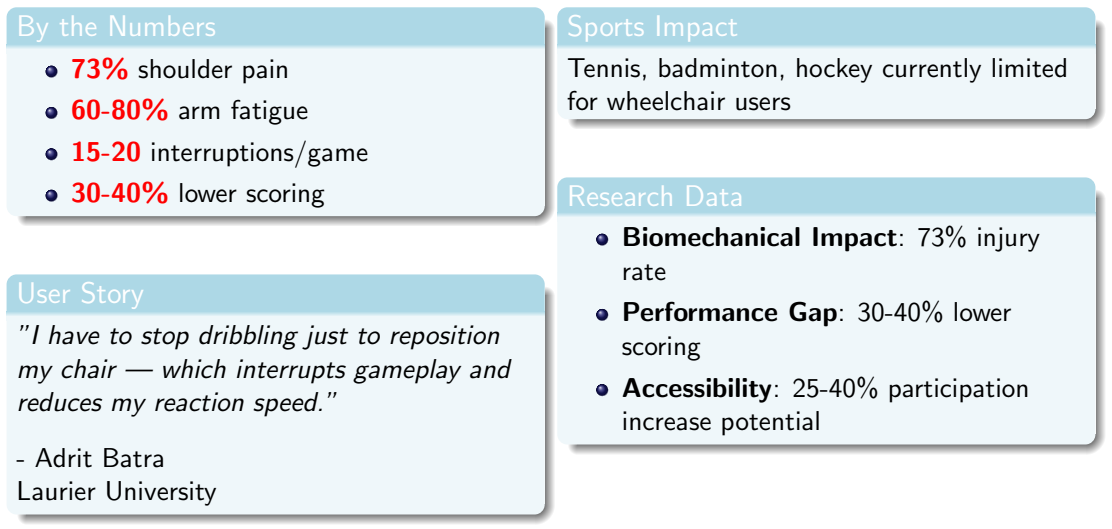
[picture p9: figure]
By the Numbers; 73% shoulder pain; 60-80% arm fatigue; 15-20 interruptions/game; 30-40% lower scoring; User Story; reduces my reaction speed.”; - Adrit Batra Laurier University; Sports Impact; Tennis, badminton, hockey currently limited for wheelchair users; Research Data; Biomechanical Impact: 73% injury rate; Performance Gap: 30-40% lower scoring; Accessibility: 25-40% participation increase potential

”I have to stop dribbling just to reposition my chair — which interrupts gameplay and

## Our Mission

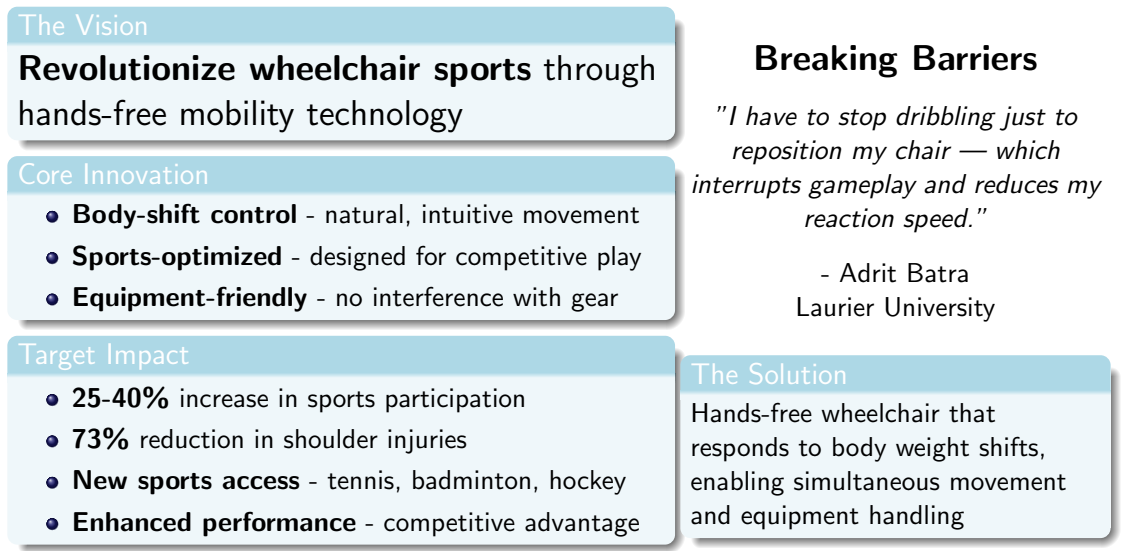
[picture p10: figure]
The Vision Revolutionize wheelchair sports through hands-free mobility technology; Core Innovation; Target Impact; 25-40% increase in sports participation; 73% reduction in shoulder injuries; Enhanced performance - competitive advantage; Breaking Barriers; ”I have to stop dribbling just to reposition my chair — which interrupts gameplay and reduces my reaction speed.”; - Adrit Batra Laurier University; The Solution; Hands-free wheelchair that responds to body weight shifts, enabling simultaneous movement and equipment handling

Body-shift control - natural, intuitive movement Sports-optimized - designed for competitive play

Equipment-friendly - no interference with gear

New sports access - tennis, badminton, hockey

## Key Engineering Specifications

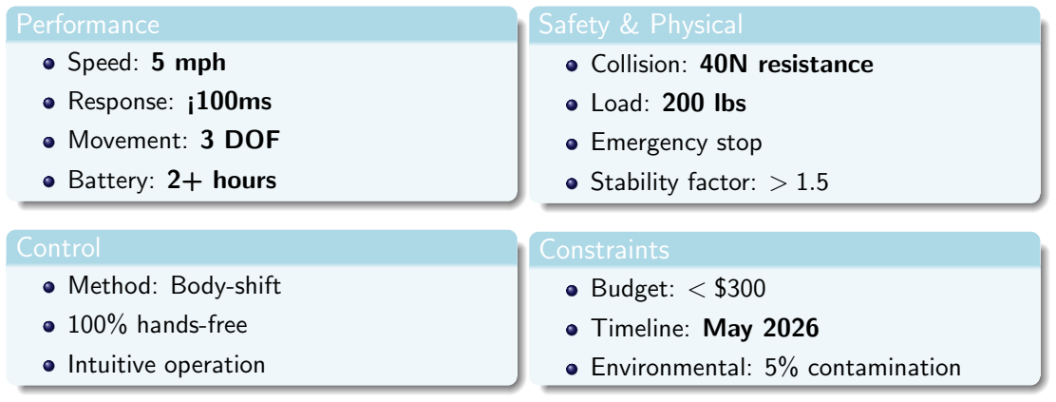
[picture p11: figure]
Performance; Speed: 5 mph; Response: ¡100ms; Movement: 3 DOF; Battery: 2+ hours; Control; Method: Body-shift; 100% hands-free; Intuitive operation; Safety & Physical; Collision: 40N resistance; Load: 200 lbs; Emergency stop; Stability factor: > 1.5; Constraints; Budget: < $300; Timeline: May 2026; Environmental: 5% contamination

## Design Constraints

Critical Requirements

C1: Hands-Free Control - 100% movement without hand input

C2: Safety - Withstand 30-50N collision forces
C3: Equipment Compatibility - No interference with sports gear C4: Environmental - Handle 5% surface contamination

C5: Response Time - < 100ms system lag
C6: Budget - < $300 total project cost

C7: Timeline - Prototype by May 2026 symposium

## Four Design Concepts Evaluated


1. Ball Drive | 2. Segway-Style
3. Mecanum Wheels | 4. Track System

## Design 1: Ball Drive System

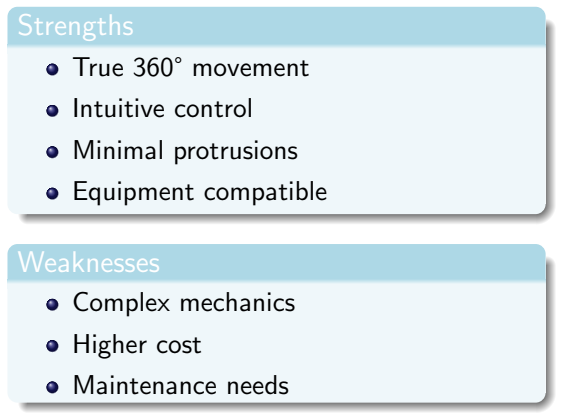
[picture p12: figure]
Strengths; True 360° movement; Intuitive control; Minimal protrusions; Equipment compatible; Weaknesses; Complex mechanics; Higher cost; Maintenance needs

## Design 2: Segway-Style Platform

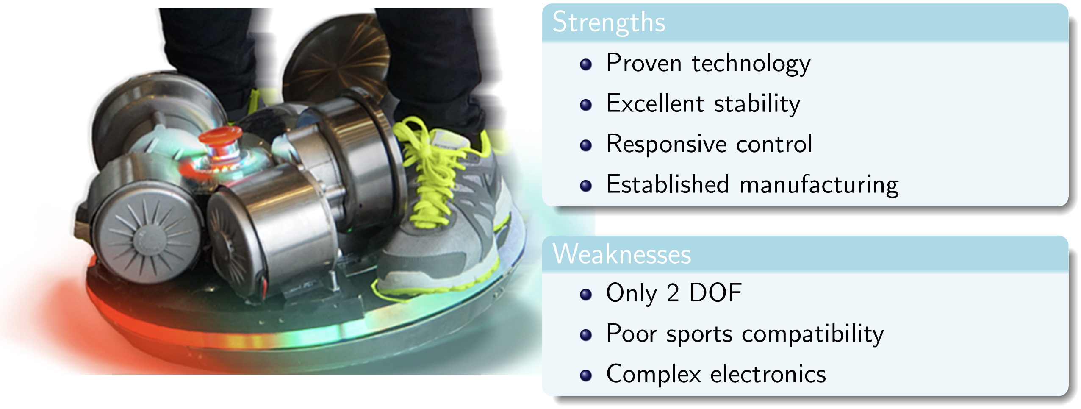
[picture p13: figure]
Strengths; Proven technology; Excellent stability; Responsive control; Established manufacturing; Weaknesses; Only 2 DOF; Poor sports compatibility; Complex electronics

## Design 3: Mecanum Wheels

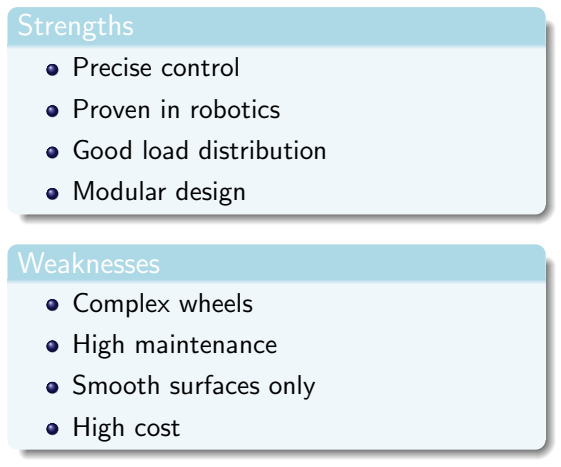
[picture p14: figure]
Strengths; Precise control; Proven in robotics; Good load distribution; Modular design; Weaknesses; Complex wheels; High maintenance; Smooth surfaces only; High cost
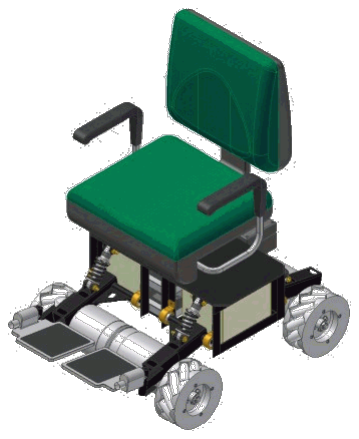
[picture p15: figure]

## Design 4: Track System

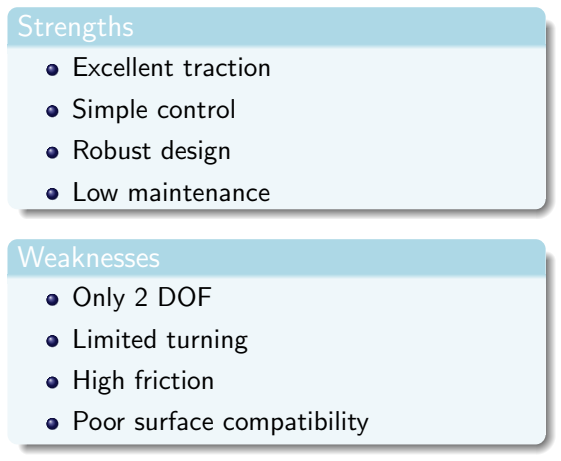
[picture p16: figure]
Strengths; Excellent traction; Simple control; Robust design; Low maintenance; Weaknesses; Only 2 DOF; Limited turning; High friction; Poor surface compatibility

## Design Selection Matrix

Criteria (Weight) | Ball | Segway | Mecanum | Track
Hands-Free (25%) | 9 | 8 | 9 | 7
Non-Interfering (20%) | 9 | 8 | 8 | 7
Responsive (20%) | 9 | 7 | 9 | 6
Equipment Compat. (15%) | 8 | 9 | 7 | 8
Safety (10%) | 7 | 9 | 8 | 9
Intuitive (5%) | 9 | 8 | 7 | 8
Full Mobility (5%) | 10 | 6 | 10 | 6
WEIGHTED SCORE | 8.6 | 7.7 | 8.3 | 7.1

## Selected: Ball Drive System (8.6/10)

## Our Selected Design

## Omni-Directional Ball Drive System

Score: 8.6/10

## Patent Landscape

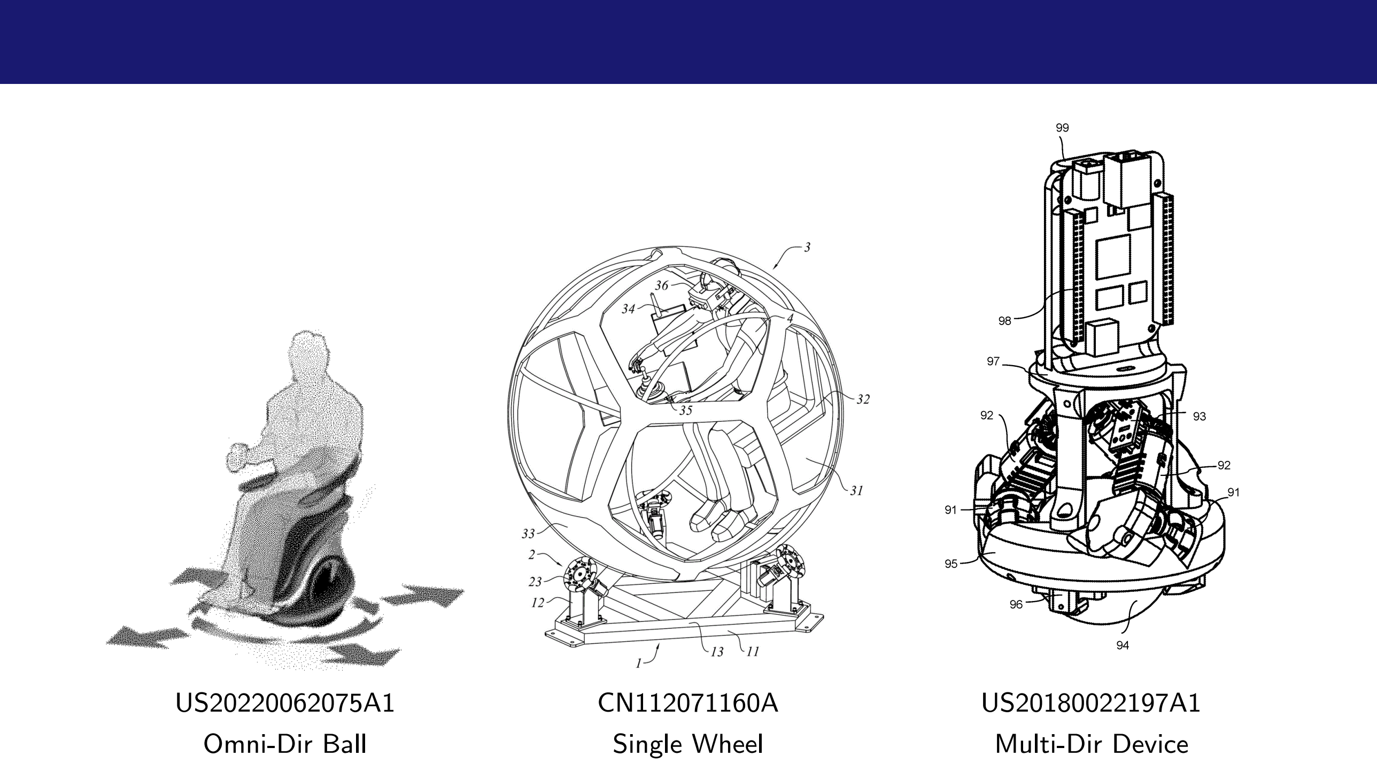
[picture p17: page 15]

US20220062075A1 | CN112071160A | US20180022197A1
Omni-Dir Ball | Single Wheel | Multi-Dir Device

## Design Freedom

## Clear Path Forward

## Our innovation:

Key Differentiators

Multi-point ball contact system Sports-specific features

Equipment compatibility focus

Modular architecture
Enhanced collision resistance

## Assessment: Clear Path Forward

## System Architecture

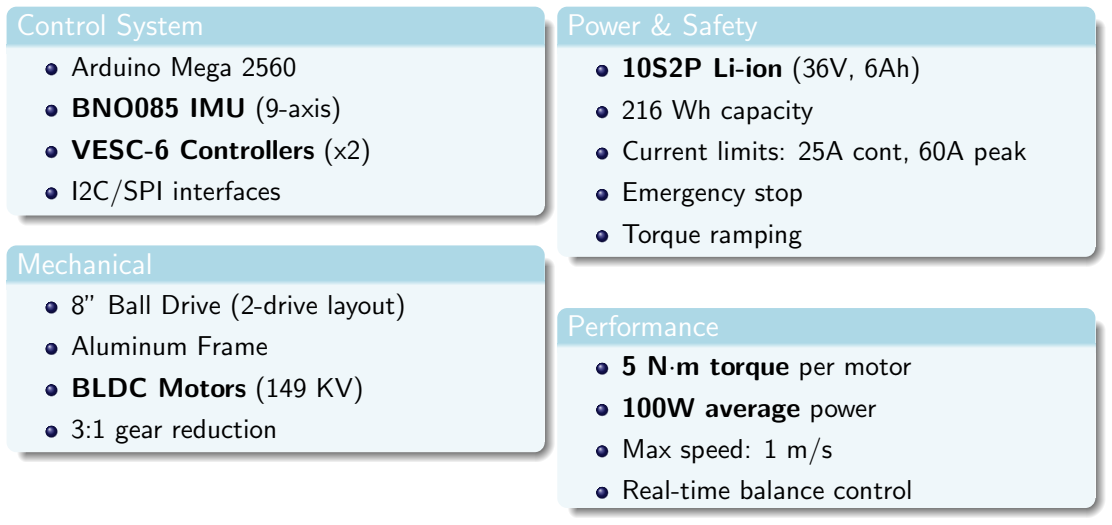
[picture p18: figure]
Control System; Arduino Mega 2560; BNO085 IMU (9-axis); VESC-6 Controllers (x2); I2C/SPI interfaces; Mechanical; 8” Ball Drive (2-drive layout); Aluminum Frame; BLDC Motors (149 KV); 3:1 gear reduction; Power & Safety; 10S2P Li-ion (36V, 6Ah); 216 Wh capacity; Current limits: 25A cont, 60A peak; Emergency stop; Torque ramping; Performance; 5 N·m torque per motor; 100W average power; Max speed: 1 m/s; Real-time balance control

## Key Performance Metrics

## Engineering Specifications Summary

Parameter | Target
Maximum Speed | 1 m/s (2.2 mph)
Response Time | < 100ms
Battery Life | > 2 hours (216 Wh)
Load Capacity | 80 kg (176 lbs)
Motor Torque | 5 N·m per motor
Motor Power | 100W average
Degrees of Freedom | 3 DOF (omni-dir)
Tipping Resistance | 40N
Operating Temperature 0-40°C

Quantified targets based on user needs and engineering analysis

## Project Timeline

## 8-Month Development Schedule

Phase/Activity | Sep | Oct | Nov | Dec | Jan | Feb | Mar | Apr

Idea Generation
Preliminary Design
PDP Presentation | | •
Design Refinement
Detailed Design
Design Verification
Final Presentation | | | | •
Assembly & Testing
Fabrication
Testing & Optimization
Symposium Prep
Symposium | | | | | | | | •

## Summary

Project Highlights

Addresses critical need in wheelchair sports Research-backed problem identification (73% injury rate) Comprehensive design evaluation (4 concepts)
Clear technical specifications (30+ parameters)
Within budget ($230-320 vs $300 limit)

Feasible 8-month timeline

## Expected Impact: 25-40% increase in wheelchair sports participation

# Thank you very much!

## Open for Questions!!

## Capstone Group 52 MTE 481 - Fall 2025

Samuel — Ameen — Joseph — Chanuth — Adesh

## Detailed Specifications

Category | Specification | Value | Justification
Mobility | Max Speed | 5 mph | Safe for indoor sports
| Acceleration | 0-5mph in 2s | Natural feel
| DOF | 3 DOF | Full mobility
Control | Response | ¡100ms | Real-time control
| IMU Rate | 100 Hz | Body tracking
Stability | CoG Height | ¡18 in | Tipping prevention
| Wheelbase | 24” x 24” | Stability polygon
Power | Battery | 7Ah @ 12V | 2+ hour runtime
| Motors | 25W each | Sufficient torque

## Component Details

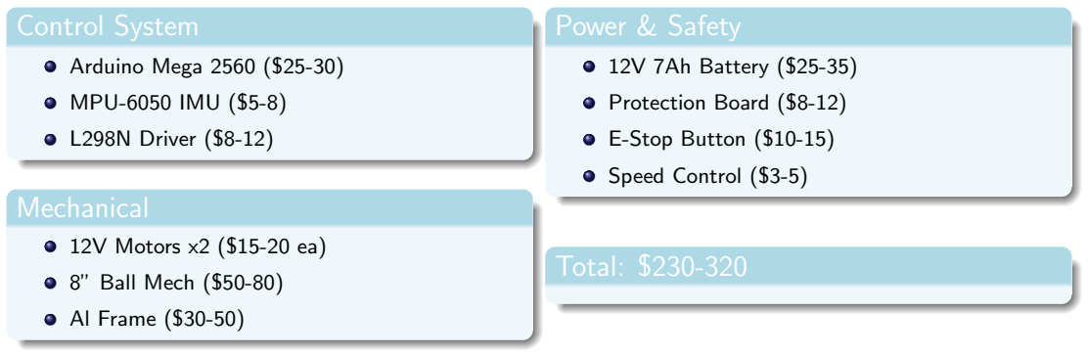
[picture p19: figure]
Control System; Arduino Mega 2560 ($25-30); MPU-6050 IMU ($5-8); L298N Driver ($8-12); Mechanical; 12V Motors x2 ($15-20 ea); 8” Ball Mech ($50-80); Al Frame ($30-50); Power & Safety; 12V 7Ah Battery ($25-35); Protection Board ($8-12); E-Stop Button ($10-15); Speed Control ($3-5); Total: $230-320

## Constraints Analysis

C1: Hands-Free - 100% movement without hand contact

C2: Safety - 30-50N collision resistance, no tipping

C3: Equipment - No interference with sports gear

C4: Environmental - 5% surface contamination tolerance

C5: Response - ¡100ms sensor-to-motor lag

C6: Budget - < $300 total cost

C7: Timeline - May 2026 deadline

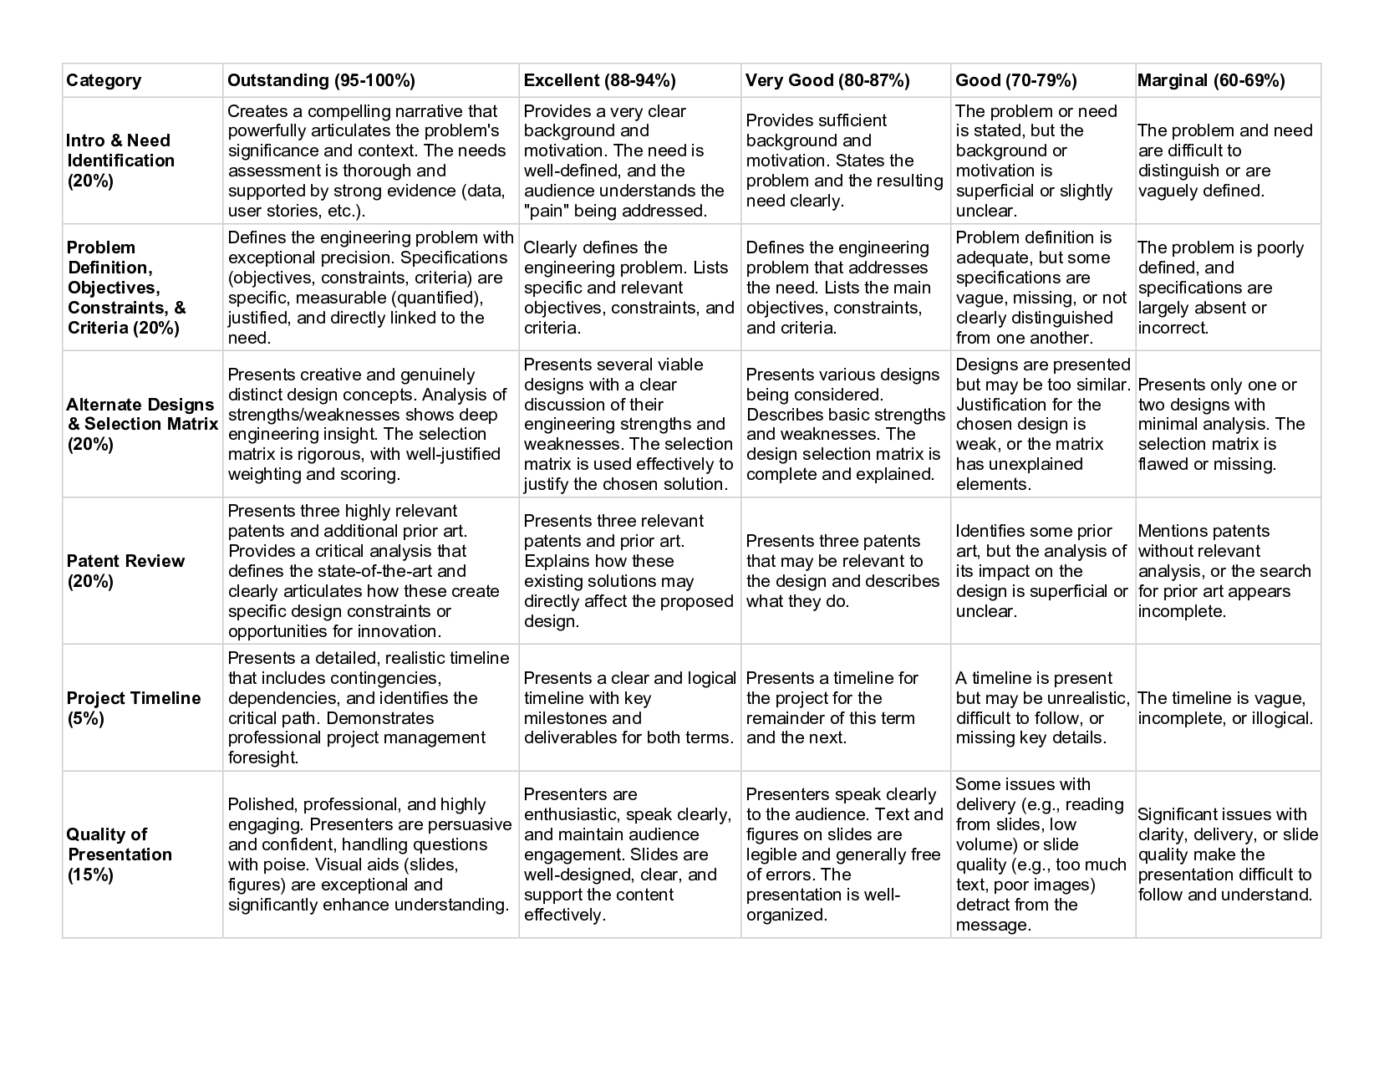
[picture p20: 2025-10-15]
courseContent/MTE481 PDP Rubric F25/MTE481 PDP Rubric F25_page-0002.jpg

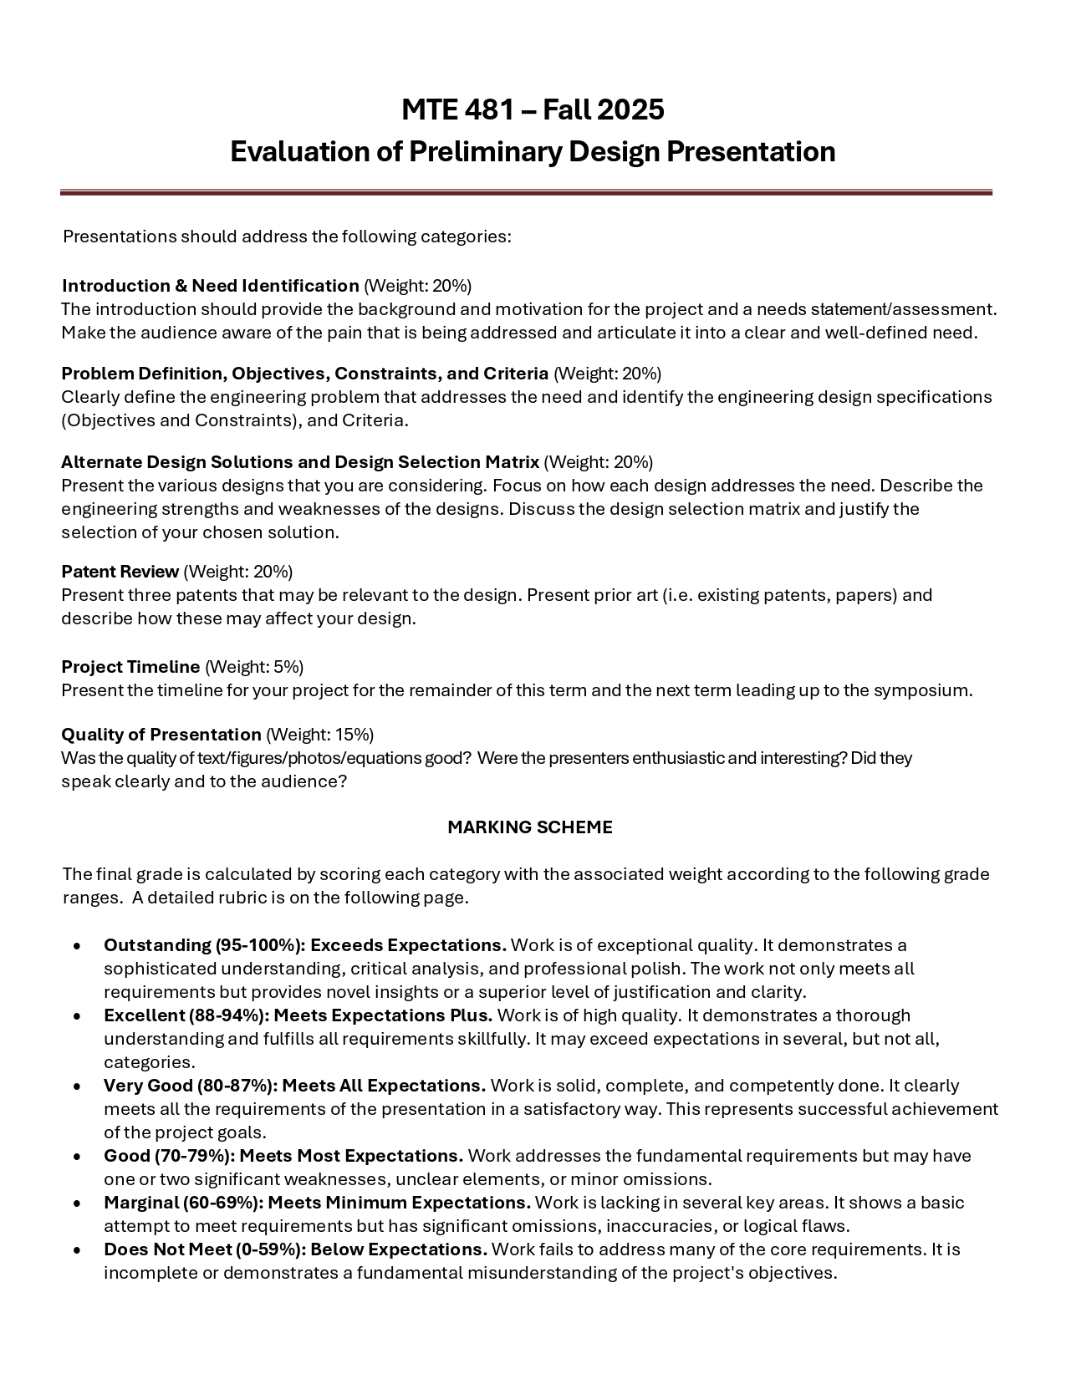
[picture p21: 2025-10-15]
courseContent/MTE481 PDP Rubric F25/MTE481 PDP Rubric F25_page-0001.jpg

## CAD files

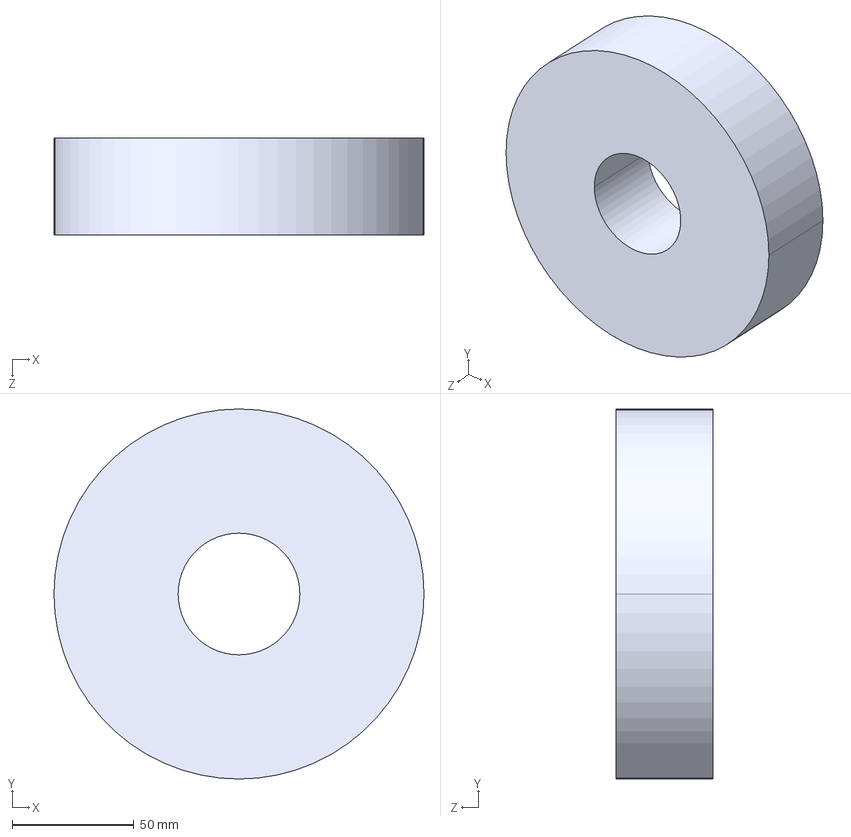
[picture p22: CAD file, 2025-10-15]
simulation/cadFiles/omni_wheel.STEP
152.0 x 152.0 x 40.0 mm

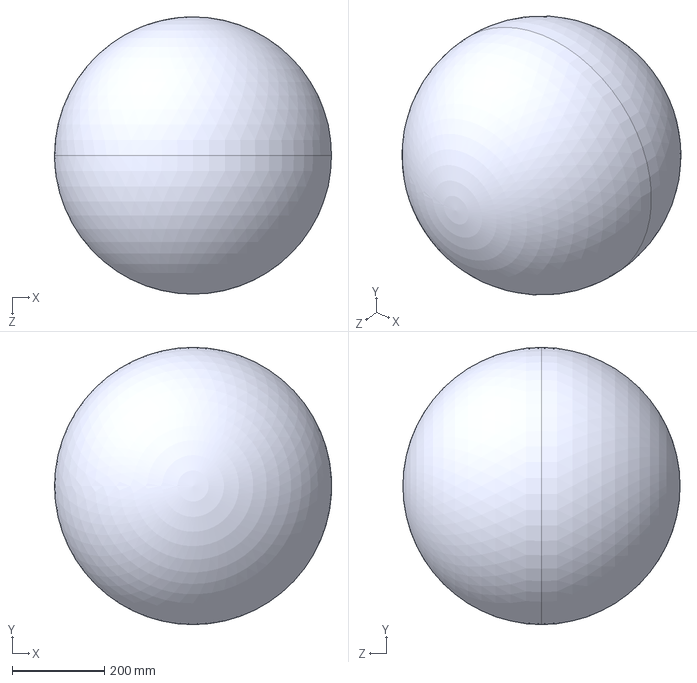
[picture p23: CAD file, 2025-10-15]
simulation/cadFiles/Ball.STEP
599.5 x 600.0 x 600.0 mm

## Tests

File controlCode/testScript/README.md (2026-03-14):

# testScript — Arduino motor outputs from simulated orientation

This folder contains scripts that replicate the **Arduino control pipeline** (from `arduinoCode/`) so you can feed in simulated orientation data and get the same motor commands the firmware would produce. Use this to verify that the simulation’s control logic matches the Arduino.

## Pipeline (matches Arduino)

1. **State**: `x = [roll, pitch, yaw, roll_dot, pitch_dot, yaw_dot]` (rad, rad/s). Optional: `INVERT_ROLL`, `IGNORE_YAW_IN_CHASSIS`.
2. **LQR**: `tau = -K @ (x - x_ref)`, then `TAU_SCALE`.
3. **IK**: Body torques → wheel torques `T1, T2, T3` (same formula as `control_helper.cpp`).
4. **Velocity**: `v1, v2, v3 = K_TAU_TO_VEL * T`, clamped, then `VEL_SCALE`.
5. **Sent to ODrive**: With `MOTOR_INVERT_V1_V2_SIGN`: `(-v1, -v2, v3)`.

Constants and order are taken from:

- `controlCode/arduinoCode/control_helper.cpp` (K*LQR, TAU_SCALE, IK, VEL*\*)
- `controlCode/arduinoCode/motor_control_helper.cpp` (MOTOR_INVERT_V1_V2_SIGN)
- `controlCode/arduinoCode/arduinoCode.ino` (INVERT_ROLL, IGNORE_YAW_IN_CHASSIS).

## Scripts

- **`run_arduino_pipeline.py`** — Run the Arduino pipeline on orientation data (single point, CSV, or from the Python balance sim). Optionally compare with simulation motor outputs (T1, T2, T3) so you can check they match.

## Usage

From project root:

```bash
# Single orientation (deg), zero angular velocity
python3 controlCode/testScript/run_arduino_pipeline.py --roll 0.5 --pitch 10 --yaw 0.5

# Continuous tilt / steady-state: torques to hold the platform at a constant tilt (zero angular velocity)
python3 controlCode/testScript/run_arduino_pipeline.py --tilt 10
#   → pitch=10°, roll=0°, yaw=0°; shows steady-state tau, T1,T2,T3, v1,v2,v3

# Steady-state with arbitrary roll/pitch/yaw
python3 controlCode/testScript/run_arduino_pipeline.py --steady-state --roll 2 --pitch 10 --yaw 0

# With angular velocities (rad/s)
python3 controlCode/testScript/run_arduino_pipeline.py --roll 0 --pitch 5 --yaw 0 --omega_r 0.01 --omega_p -0.02 --omega_y 0

# From CSV: columns roll_deg, pitch_deg, yaw_deg [, omega_r, omega_p, omega_y]
python3 controlCode/testScript/run_arduino_pipeline.py --csv path/to/orientation_log.csv

# Run balance sim for N seconds, log state, run Arduino pipeline on each row and compare to sim motors
python3 controlCode/testScript/run_arduino_pipeline.py --sim 5 --out comparison.csv
```

The script prints (and optionally writes) Arduino outputs: `tau_roll, tau_pitch, tau_yaw`, `T1, T2, T3`, `v1, v2, v3`, and `sent_v1, sent_v2, sent_v3` when applicable.

**Note:** The simulation uses the full LQR output (no `TAU_SCALE`) for physics, while the Arduino applies `TAU_SCALE = 0.01` before IK. So `T1,T2,T3` from the Arduino pipeline will be much smaller in magnitude than the simulation’s motor torques; the comparison is mainly for sign and direction consistency.

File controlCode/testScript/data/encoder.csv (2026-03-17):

time | e1 | e2 | e3
0.0 | 0.0 | 0.0 | 0.0
0.0667714579612948 | 0.0 | 0.0 | 0.0
0.1028984579606913 | 0.0 | 0.0 | 0.0
0.16682374995434657 | 0.0 | 0.0 | 0.0
0.23283941694535315 | 0.0 | 0.0 | 0.0
0.25860316696343943 | 0.0 | 0.0 | 0.0
0.3158444579457864 | 0.0 | 0.0 | 0.0
0.36694920796435326 | 0.0 | 0.0 | 0.0
0.43357633298728615 | 0.0 | 0.0 | 0.0
0.5002699999604374 | 0.0 | 0.0 | 0.0
0.5361517919809557 | 0.0 | 0.0 | 0.0
0.599593416962307 | 0.0 | 0.0 | 0.0
0.6587698749499395 | 0.0 | 0.0 | 0.0
0.6941106249578297 | 0.0 | 0.0 | 0.0
0.757869666966144 | 0.0 | 0.0 | 0.0
0.816530457988847 | 0.0 | 0.0 | 0.0
0.8516838749637827 | 0.0 | 0.0 | 0.0
0.9160657079773955 | 0.0 | 0.0 | 0.0
0.9661383329657838 | 0.0 | 0.0 | 0.0
1.0256557919783518 | 0.0 | 0.0 | 0.0
1.0907849169452675 | 0.0 | 0.0 | 0.0
1.1408379579661414 | 0.0 | 0.0 | 0.0
1.1999267499777488 | 0.0 | 0.0 | 0.0
1.2355951249483041 | 0.0 | 0.0 | 0.0
1.3000895419972949 | 0.0 | 0.0 | 0.0
1.3353024579701014 | 0.0 | 0.0 | 0.0
1.3992564169457182 | 0.0 | 0.0 | 0.0
1.4499035829794593 | 0.0 | 0.0 | 0.0
1.51647954195505 | 0.0 | 0.0 | 0.0
1.5839614579454064 | 0.0 | 0.0 | 0.0
1.61958112497814 | 0.0 | 0.0 | 0.0
1.6825680829933845 | 0.0 | 0.0 | 0.0
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

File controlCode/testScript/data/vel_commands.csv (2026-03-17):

time | v1 | v2 | v3
0.0 | 0.366 | -0.732 | 0.366
0.0667714579612948 | 0.363 | -0.726 | 0.363
0.1028984579606913 | 0.277 | -0.553 | 0.277
0.16682374995434657 | 0.355 | -0.71 | 0.355
0.23283941694535315 | 0.352 | -0.705 | 0.352
0.25860316696343943 | 0.35 | -0.701 | 0.35
0.3158444579457864 | 0.349 | -0.698 | 0.349
0.36694920796435326 | 0.348 | -0.697 | 0.348
0.43357633298728615 | 0.349 | -0.698 | 0.349
0.5002699999604374 | 0.35 | -0.699 | 0.35
0.5361517919809557 | 0.35 | -0.7 | 0.35
0.599593416962307 | 0.351 | -0.703 | 0.351
0.6587698749499395 | 0.352 | -0.704 | 0.352
0.6941106249578297 | 0.353 | -0.706 | 0.353
0.757869666966144 | 0.326 | -0.651 | 0.326
0.816530457988847 | 0.347 | -0.694 | 0.347
0.8516838749637827 | 0.351 | -0.703 | 0.351
0.9160657079773955 | 0.351 | -0.702 | 0.351
0.9661383329657838 | 0.349 | -0.699 | 0.349
1.0256557919783518 | 0.348 | -0.696 | 0.348
1.0907849169452675 | 0.346 | -0.693 | 0.346
1.1408379579661414 | 0.344 | -0.688 | 0.344
1.1999267499777488 | 0.339 | -0.679 | 0.339
1.2355951249483041 | 0.335 | -0.671 | 0.335
1.3000895419972949 | 0.33 | -0.659 | 0.33
1.3353024579701014 | 0.324 | -0.648 | 0.324
1.3992564169457182 | 0.317 | -0.633 | 0.317
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

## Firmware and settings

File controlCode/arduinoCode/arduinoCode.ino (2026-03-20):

/*
 * Modular dual-IMU + ODrive: LQR or PID outer loop (chassis-only, ref = upright), inner loop motor velocity PI.
 * Motor 1=roll, Motor 2=pitch, Motor 3=yaw. State from IMU A; roll/pitch axes swapped to match hardware.
 */
#include "config.h"

#define SERIAL_PRINT_INTERVAL_MS  50
#define TUNE_PRINT_INTERVAL_MS    1000U  // Print pot tuning values to serial every 1s when any USE_POT_TUNE_* is 1

// Software reset test: 1 = reset every 30s to re-run setup()/init; 0 = disabled.
#define ENABLE_SOFTWARE_RESET_TEST  0
#define SOFT_RESET_TEST_INTERVAL_MS  30000U

// Minimum velocity magnitude to overcome stiction per motor (small non-zero commands snapped to ±min).
#define STICTION_MIN_V1    0.0f
#define STICTION_MIN_V2    0.0f
#define STICTION_MIN_V3    0.0f

#include "sensor_helper.h"
#include "control_helper.h"
#include "motor_control_helper.h"

#if USE_POT_MOTOR_VELOCITY
static float potToVelocity(int raw) {
  if (raw <= POT_DEADZONE) return 0.0f;
  float n = (float)(raw - POT_DEADZONE) / (POT_ANALOG_MAX - (float)POT_DEADZONE);
  if (n > 1.0f) n = 1.0f;
#if POT_VELOCITY_POSITIVE
  return n * POT_VEL_RANGE;   // 0 to +POT_VEL_RANGE
#else
  return -n * POT_VEL_RANGE;  // 0 to -POT_VEL_RANGE
#endif
}
#endif

#if USE_POT_TORQUE
static float potToTau(int raw) {
  if (raw <= POT_TAU_DEADZONE) return 0.0f;
  float n = (float)(raw - POT_TAU_DEADZONE) / (POT_TAU_ANALOG_MAX - (float)POT_TAU_DEADZONE);
  if (n > 1.0f) n = 1.0f;
#if POT_TAU_POSITIVE
  return n * POT_TAU_RANGE;   // full range: 0 to +POT_TAU_RANGE
#else
  return -n * POT_TAU_RANGE;  // full range: 0 to -POT_TAU_RANGE
#endif
}
#endif

static float applyManualStiction(float v_cmd, float min_mag) {
  if (min_mag <= 0.0f) return v_cmd;
  if (v_cmd > 0.0f && v_cmd < min_mag) return min_mag;
  if (v_cmd < 0.0f && -v_cmd < min_mag) return -min_mag;
  return v_cmd;
}

#if USE_POT_TUNE_PLANT || (USE_POT_TUNE_OUTER_PID && USE_PID_OUTER) || USE_POT_TUNE_INNER
// Returns normalized 0..1 from potentiometer (deadzone at low end).
static float readPotTune(int pin, int deadzone, float analog_max) {
  int raw = analogRead(pin);
  if (raw <= deadzone) return 0.0f;
  if (raw >= (int)analog_max) return 1.0f;
  return (float)(raw - deadzone) / (analog_max - (float)deadzone);
}
static float lerpf(float lo, float hi, float t) {
  if (t <= 0.0f) return lo;
  if (t >= 1.0f) return hi;
  return lo + t * (hi - lo);
}
#endif

static void printHeader(void) {
  Serial.println("IMU_A: Roll   Pitch  Yaw   | omega_R   omega_P   omega_Y (rad/s) | tau_R   tau_P   tau_Y  | n0 n1 n2  | v1    v2    v3 (rev/s) | v1_des v2_des v3_des | e1    e2    e3  | p1    p2    p3 (rev)");
}

static void printRow(float rollA, float pitchA, float yawA, float omega_r, float omega_p, float omega_y, float tau_r, float tau_p, float tau_y, float v1, float v2, float v3, float v1_des, float v2_des, float v3_des, float e1, float e2, float e3, float p1, float p2, float p3) {
  Serial.print(rollA, 2);  Serial.print(" ");
  Serial.print(pitchA, 2); Serial.print(" ");
  Serial.print(yawA, 2);  Serial.print("  | ");
  Serial.print(omega_r, 4); Serial.print(" ");
  Serial.print(omega_p, 4); Serial.print(" ");
  Serial.print(omega_y, 4); Serial.print("  | ");
  Serial.print(tau_r, 3); Serial.print(" ");
  Serial.print(tau_p, 3); Serial.print(" ");
  Serial.print(tau_y, 3); Serial.print("  | ");
  Serial.print(motor_isNodePresent(0) ? "1" : "0"); Serial.print(" ");
  Serial.print(motor_isNodePresent(1) ? "1" : "0"); Serial.print(" ");
  Serial.print(motor_isNodePresent(2) ? "1" : "0"); Serial.print("  | ");
  Serial.print(v1, 3); Serial.print(" ");
  Serial.print(v2, 3); Serial.print(" ");
  Serial.print(v3, 3); Serial.print("  | ");
  Serial.print(v1_des, 3); Serial.print(" ");
  Serial.print(v2_des, 3); Serial.print(" ");
  Serial.print(v3_des, 3); Serial.print("  | ");
  Serial.print(e1, 3); Serial.print(" ");
  Serial.print(e2, 3); Serial.print(" ");
  Serial.print(e3, 3); Serial.print("  | ");
  Serial.print(p1, 4); Serial.print(" ");
  Serial.print(p2, 4); Serial.print(" ");
  Serial.println(p3, 4);
}

#if ENABLE_RESET_BUTTON
// Call repeatedly from setup() retry loops so the button can trigger reset when stuck.
static void checkResetButton(void) {
  static uint32_t low_since = 0;
  if (digitalRead(RESET_BUTTON_PIN) == LOW) {
    if (low_since == 0)
      low_since = millis();
    else if (millis() - low_since >= 30) {
      Serial.println("Reset button pressed — software reset");
      Serial.flush();
      (*(volatile uint32_t *)0xE000ED0C) = 0x05FA0004;
      for (;;) { }
    }
  } else {
    low_since = 0;
  }
}
#endif

void setup() {
#if ENABLE_RESET_BUTTON
  pinMode(RESET_BUTTON_PIN, INPUT_PULLUP);
#endif
  Serial.begin(115200);
  for (int i = 0; i < 30 && !Serial; ++i) delay(100);
  delay(200);

  Serial.println("=== Outer (LQR or PID) + motor velocity PI (sensor -> control -> motor) ===");

  // After software reset, give I2C and IMUs time to be ready.
  delay(400);

  while (!sensor_init()) {
#if USE_IMU_B_AS_A
    Serial.println("Sensor init failed (IMU B @0x4B only; IMU A skipped), retrying in 2s...");
#elif USE_IMU_B
    Serial.println("Sensor init failed (IMU A or B not found), retrying in 2s...");
#else
    Serial.println("Sensor init failed (IMU A not found), retrying in 2s...");
#endif
    sensor_release_bus_for_retry();  // Release I2C so BNO08x can clear stuck state
    for (uint32_t t = millis(); millis() - t < 2000; ) {
#if ENABLE_RESET_BUTTON
      checkResetButton();
#endif
      delay(50);
    }
  }
#if USE_IMU_B_AS_A
  Serial.println("IMU B @0x4B OK (USE_IMU_B_AS_A: platform uses B; 0x4A not initialized).");
#elif USE_IMU_B
  Serial.println("IMU A and B OK");
#else
  Serial.println("IMU A OK (USE_IMU_B=0: IMU B skipped, control axis = IMU A)");
#endif

  sensor_calibrateZero();
  float rz, pz, yz;
  sensor_getEulerZeroRad(&rz, &pz, &yz);
#if USE_IMU_B_AS_A
  Serial.print("Euler zero mirror (rad) roll=");
#elif USE_IMU_B
  Serial.print("IMU B zero (rad) roll=");
#else
  Serial.print("Euler zero / IMU B mirror (rad) roll=");
#endif
  Serial.print(rz, 4);
  Serial.print(" pitch="); Serial.print(pz, 4);
  Serial.print(" yaw="); Serial.println(yz, 4);
  sensor_getPlatformZeroRad(&rz, &pz, &yz);
  Serial.print("Platform zero (rad) roll="); Serial.print(rz, 4);
  Serial.print(" pitch="); Serial.print(pz, 4);
  Serial.print(" yaw="); Serial.println(yz, 4);

  if (!motor_init()) {
    Serial.println("Motor init failed");
    while (true) {
#if ENABLE_RESET_BUTTON
      checkResetButton();
#endif
      delay(100);
    }
  }

  Serial.println("Listening for ODrive heartbeats 1.5s...");
  uint32_t start = millis();
  while (millis() - start < 1500) {
    motor_pumpEvents();
    delay(10);
  }
  Serial.print("Nodes: n0="); Serial.print(motor_isNodePresent(0));
  Serial.print(" n1="); Serial.print(motor_isNodePresent(1));
  Serial.print(" n2="); Serial.println(motor_isNodePresent(2));

  control_computeKAtInit();
  control_setVelScaleAndMax(VEL_SCALE, VEL_MAX);
  control_setUseLQRLookup(0);

#if USE_POT_TORQUE
  Serial.println("Mode: Pot torque — pots set tau_roll, tau_pitch, tau_yaw (no LQR).");
#elif USE_POT_MOTOR_VELOCITY
  Serial.println("Mode: Pot velocity — pots set v1,v2,v3 directly (no LQR).");
#else
#if USE_PID_OUTER
  Serial.println("Mode: PID outer (x_ref = 0) + inner velocity PI.");
#else
  Serial.println("Mode: LQR outer (x_ref = 0) + inner velocity PI.");
#endif
#endif
  Serial.println("Platform: IMU A. Roll/pitch swap: ON.");
  printHeader();

#if ENABLE_RESET_BUTTON
  Serial.print("Reset button on pin ");
  Serial.println(RESET_BUTTON_PIN);
#endif
}

void loop() {
  motor_pumpEvents();

#if ENABLE_RESET_BUTTON
  {
    static uint32_t reset_btn_low_since = 0;
    if (digitalRead(RESET_BUTTON_PIN) == LOW) {
      if (reset_btn_low_since == 0)
        reset_btn_low_since = millis();
      else if (millis() - reset_btn_low_since >= 30) {
        Serial.println("Reset button pressed — software reset");
        Serial.flush();
        (*(volatile uint32_t *)0xE000ED0C) = 0x05FA0004;
        for (;;) { }
      }
    } else {
      reset_btn_low_since = 0;
    }
  }
#endif

#if ENABLE_SOFTWARE_RESET_TEST
  if (millis() >= SOFT_RESET_TEST_INTERVAL_MS) {
    Serial.println("Software reset (30s test)...");
    Serial.flush();
    // ARM Cortex-M7 system reset (Teensy 4.1)
    (*(volatile uint32_t *)0xE000ED0C) = 0x05FA0004;
    for (;;) { }
  }
#endif

  static uint32_t last_print = 0;

#if USE_POT_TORQUE
  float tau_roll  = potToTau(analogRead(POT_PIN_TAU_ROLL));
  float tau_pitch = potToTau(analogRead(POT_PIN_TAU_PITCH));
  float tau_yaw   = potToTau(analogRead(POT_PIN_TAU_YAW));
  float v1, v2, v3;
  control_bodyTorqueToVelocity(tau_roll, tau_pitch, tau_yaw, &v1, &v2, &v3);
  v1 = applyManualStiction(v1, STICTION_MIN_V1);
  v2 = applyManualStiction(v2, STICTION_MIN_V2);
  v3 = applyManualStiction(v3, STICTION_MIN_V3);
  motor_sendVelocities(v1, v2, v3);

  if (millis() - last_print > SERIAL_PRINT_INTERVAL_MS) {
    last_print = millis();
    float dummy;
    sensor_readImuA(&dummy);
    sensor_readControlAxis(&dummy);
    const float rad2deg = 180.0f / PI;
    float x[6], pr0, pp0, py0;
    sensor_getImuA_StateRad(&x[0], &x[1], &x[2], &x[3], &x[4], &x[5]);
    sensor_getPlatformZeroRad(&pr0, &pp0, &py0);
    x[0] -= pr0; x[1] -= pp0; x[2] -= py0;
    float tmp_ax = x[0]; x[0] = x[1]; x[1] = tmp_ax;
    float tmp_omega = x[3]; x[3] = x[4]; x[4] = tmp_omega;
    x[1] = -x[1]; x[4] = -x[4];
    float yawA, pitchA, rollA;
    sensor_getImuA_EulerDeg(&yawA, &pitchA, &rollA);
    float roll_z  = rollA  - (pr0 * rad2deg);
    float pitch_z = pitchA - (pp0 * rad2deg);
    float yaw_z   = yawA   - (py0 * rad2deg);
    float disp_roll = pitch_z;
    float disp_pitch = -roll_z;
    float disp_omega_r = x[3];
    float disp_omega_p = x[4];
    motor_requestEncoderFeedback();
    float e1, e2, e3, p1, p2, p3;
    motor_getEncoderVelocities(&e1, &e2, &e3);
    motor_getEncoderPositions(&p1, &p2, &p3);
    printRow(disp_roll, disp_pitch, yaw_z, disp_omega_r, disp_omega_p, x[5], tau_roll, tau_pitch, tau_yaw, v1, v2, v3, v1, v2, v3, e1, e2, e3, p1, p2, p3);
  }
  delay(10);
  return;
#elif USE_POT_MOTOR_VELOCITY
  float v1 = potToVelocity(analogRead(POT_PIN_M1));
  float v2 = potToVelocity(analogRead(POT_PIN_M2));
  float v3 = potToVelocity(analogRead(POT_PIN_M3));
  motor_sendVelocities(v1, v2, v3);

  if (millis() - last_print > SERIAL_PRINT_INTERVAL_MS) {
    last_print = millis();
    float dummy;
    sensor_readImuA(&dummy);
    sensor_readControlAxis(&dummy);
    const float rad2deg = 180.0f / PI;
    float x[6], pr0, pp0, py0;
    sensor_getImuA_StateRad(&x[0], &x[1], &x[2], &x[3], &x[4], &x[5]);
    sensor_getPlatformZeroRad(&pr0, &pp0, &py0);
    x[0] -= pr0; x[1] -= pp0; x[2] -= py0;
    float tmp_ax = x[0]; x[0] = x[1]; x[1] = tmp_ax;
    float tmp_omega = x[3]; x[3] = x[4]; x[4] = tmp_omega;
    x[1] = -x[1]; x[4] = -x[4];
    float yawA, pitchA, rollA;
    sensor_getImuA_EulerDeg(&yawA, &pitchA, &rollA);
    float roll_z  = rollA  - (pr0 * rad2deg);
    float pitch_z = pitchA - (pp0 * rad2deg);
    float yaw_z   = yawA   - (py0 * rad2deg);
    float disp_roll = pitch_z;
    float disp_pitch = -roll_z;
    float disp_omega_r = x[3];
    float disp_omega_p = x[4];
    motor_requestEncoderFeedback();
    float e1, e2, e3, p1, p2, p3;
    motor_getEncoderVelocities(&e1, &e2, &e3);
    motor_getEncoderPositions(&p1, &p2, &p3);
    printRow(disp_roll, disp_pitch, yaw_z, disp_omega_r, disp_omega_p, x[5], 0.0f, 0.0f, 0.0f, v1, v2, v3, v1, v2, v3, e1, e2, e3, p1, p2, p3);
  }
  delay(10);
  return;
#else
  static uint32_t last_outer_ms = 0;
  static uint32_t last_inner_ms = 0;
  static float v_des[3] = { 0.0f, 0.0f, 0.0f };
  static float last_disp_roll = 0.0f, last_disp_pitch = 0.0f, last_yaw_z = 0.0f;
  static float last_disp_omega_r = 0.0f, last_disp_omega_p = 0.0f, last_x5 = 0.0f;
  static float last_tau_roll = 0.0f, last_tau_pitch = 0.0f, last_tau_yaw = 0.0f;
  static float last_v_cmd[3] = { 0.0f, 0.0f, 0.0f };
  static float last_e1 = 0.0f, last_e2 = 0.0f, last_e3 = 0.0f, last_p1 = 0.0f, last_p2 = 0.0f, last_p3 = 0.0f;

  const uint32_t outer_period_ms = 1000U / (uint32_t)OUTER_LOOP_HZ;
  const uint32_t inner_period_ms = 1000U / (uint32_t)INNER_LOOP_HZ;
  uint32_t now_ms = millis();

  // Outer loop (IMU + LQR or PID): update v_des at OUTER_LOOP_HZ.
  if (now_ms - last_outer_ms >= outer_period_ms) {
    last_outer_ms = now_ms;
    float dummy;
    sensor_readImuA(&dummy);
    sensor_readControlAxis(&dummy);
    float x[6], x_ref[6];
    sensor_getImuA_StateRad(&x[0], &x[1], &x[2], &x[3], &x[4], &x[5]);
    float pr0, pp0, py0;
    sensor_getPlatformZeroRad(&pr0, &pp0, &py0);
    x[0] -= pr0; x[1] -= pp0; x[2] -= py0;
    x_ref[0] = 0.0f; x_ref[1] = 0.0f; x_ref[2] = 0.0f;
    x_ref[3] = 0.0f; x_ref[4] = 0.0f; x_ref[5] = 0.0f;
    float tmp_ax = x[0]; x[0] = x[1]; x[1] = tmp_ax;
    float tmp_omega = x[3]; x[3] = x[4]; x[4] = tmp_omega;
    float tmp_ref = x_ref[0]; x_ref[0] = x_ref[1]; x_ref[1] = tmp_ref;
    x[1] = -x[1]; x[4] = -x[4];

#if USE_POT_TUNE_PLANT
    {
      float t1 = readPotTune(POT_TUNE_PIN_PLANT, POT_TUNE_DEADZONE, POT_TUNE_ANALOG_MAX);
      control_setPlantParams(
          lerpf(POT_TUNE_PLANT_M_MIN,  POT_TUNE_PLANT_M_MAX,  t1),
          lerpf(POT_TUNE_PLANT_J_MIN,  POT_TUNE_PLANT_J_MAX,  t1),
          lerpf(POT_TUNE_PLANT_J_MIN,  POT_TUNE_PLANT_J_MAX,  t1),
          lerpf(POT_TUNE_PLANT_H_MIN,  POT_TUNE_PLANT_H_MAX,  t1),
          lerpf(POT_TUNE_PLANT_X_MIN,  POT_TUNE_PLANT_X_MAX,  t1));
    }
#endif
#if USE_POT_TUNE_OUTER_PID && USE_PID_OUTER
    {
      float t2 = readPotTune(POT_TUNE_PIN_OUTER_PID, POT_TUNE_DEADZONE, POT_TUNE_ANALOG_MAX);
      float okp = lerpf(POT_TUNE_OUTER_KP_MIN, POT_TUNE_OUTER_KP_MAX, t2);
      float oki = lerpf(POT_TUNE_OUTER_KI_MIN, POT_TUNE_OUTER_KI_MAX, t2);
      float okd = lerpf(POT_TUNE_OUTER_KD_MIN, POT_TUNE_OUTER_KD_MAX, t2);
      control_setOuterPIDGainsRollPitch(okp, oki, okd, okp, oki, okd);
    }
#endif
#if USE_POT_TUNE_INNER
    {
      float t3 = readPotTune(POT_TUNE_PIN_INNER, POT_TUNE_DEADZONE, POT_TUNE_ANALOG_MAX);
      control_setInnerPIDGains(
          lerpf(POT_TUNE_INNER_KP_HIGH_MIN, POT_TUNE_INNER_KP_HIGH_MAX, t3),
          lerpf(POT_TUNE_INNER_KP_MIN,      POT_TUNE_INNER_KP_MAX,      t3),
          lerpf(POT_TUNE_INNER_KI_MIN,      POT_TUNE_INNER_KI_MAX,      t3),
          lerpf(POT_TUNE_INNER_KD_MIN,      POT_TUNE_INNER_KD_MAX,      t3));
    }
#endif

    float tau_roll, tau_pitch, tau_yaw;
#if USE_PID_OUTER
    control_updatePID(x, x_ref, &v_des[0], &v_des[1], &v_des[2], &tau_roll, &tau_pitch, &tau_yaw);
#else
    control_updateLQR(x, x_ref, &v_des[0], &v_des[1], &v_des[2], &tau_roll, &tau_pitch, &tau_yaw);
#endif
    last_tau_roll = tau_roll; last_tau_pitch = tau_pitch; last_tau_yaw = tau_yaw;
    last_disp_omega_r = x[3]; last_disp_omega_p = x[4]; last_x5 = x[5];
    const float rad2deg = 180.0f / PI;
    float yawA, pitchA, rollA;
    sensor_getImuA_EulerDeg(&yawA, &pitchA, &rollA);
    float roll_z  = rollA  - (pr0 * rad2deg);
    float pitch_z = pitchA - (pp0 * rad2deg);
    float yaw_z   = yawA   - (py0 * rad2deg);
    last_disp_roll = pitch_z; last_disp_pitch = -roll_z; last_yaw_z = yaw_z;
  }

  // Inner loop (encoder + velocity PI + motors): run at INNER_LOOP_HZ, must be >= outer.
  if (now_ms - last_inner_ms >= inner_period_ms) {
    uint32_t inner_elapsed_ms = now_ms - last_inner_ms;
    last_inner_ms = now_ms;
    float dt_s = (float)inner_elapsed_ms * 0.001f;
    if (dt_s <= 0.0f || dt_s > 0.2f) dt_s = 1.0f / (float)INNER_LOOP_HZ;
    float v_act[3], v_cmd[3];
    motor_requestEncoderFeedback();
    motor_getEncoderVelocities(&v_act[0], &v_act[1], &v_act[2]);
    control_innerVelocityPI(v_des, v_act, dt_s, v_cmd);
    // When setpoint is near zero, allow zero command (don't snap to ±min); else apply stiction.
    for (int i = 0; i < 3; i++) {
      float min_mag = (i == 0) ? STICTION_MIN_V1 : (i == 1) ? STICTION_MIN_V2 : STICTION_MIN_V3;
      if (fabsf(v_des[i]) < 0.05f && fabsf(v_cmd[i]) < min_mag)
        v_cmd[i] = 0.0f;
      else
        v_cmd[i] = applyManualStiction(v_cmd[i], min_mag);
    }
    motor_sendVelocities(v_cmd[0], v_cmd[1], v_cmd[2]);
    last_v_cmd[0] = v_cmd[0]; last_v_cmd[1] = v_cmd[1]; last_v_cmd[2] = v_cmd[2];
    last_e1 = v_act[0]; last_e2 = v_act[1]; last_e3 = v_act[2];
    motor_getEncoderPositions(&last_p1, &last_p2, &last_p3);
  }

  if (millis() - last_print > SERIAL_PRINT_INTERVAL_MS) {
    last_print = millis();
    printRow(last_disp_roll, last_disp_pitch, last_yaw_z, last_disp_omega_r, last_disp_omega_p, last_x5,
             last_tau_roll, last_tau_pitch, last_tau_yaw, last_v_cmd[0], last_v_cmd[1], last_v_cmd[2],
             v_des[0], v_des[1], v_des[2],
             last_e1, last_e2, last_e3, last_p1, last_p2, last_p3);
  }

#if (USE_POT_TUNE_PLANT || (USE_POT_TUNE_OUTER_PID && USE_PID_OUTER) || USE_POT_TUNE_INNER)
  {
    static uint32_t last_tune_print = 0;
    if (millis() - last_tune_print >= TUNE_PRINT_INTERVAL_MS) {
      last_tune_print = millis();
      float M, Jr, Jp, H, Xcm, kph, kpb, ki_in, kd_in;
      float okpr, okir, okdr, okpp, okip, okdp;
      control_getPlantParams(&M, &Jr, &Jp, &H, &Xcm);
      control_getOuterPIDGainsRollPitch(&okpr, &okir, &okdr, &okpp, &okip, &okdp);
      control_getInnerPIDGains(&kph, &kpb, &ki_in, &kd_in);
      Serial.print("TUNE ");
#if USE_POT_TUNE_PLANT
      Serial.print("M="); Serial.print(M, 1); Serial.print(" J="); Serial.print(Jr, 1); Serial.print(" H="); Serial.print(H, 2); Serial.print(" X="); Serial.print(Xcm, 3);
#endif
#if USE_POT_TUNE_PLANT && ((USE_POT_TUNE_OUTER_PID && USE_PID_OUTER) || USE_POT_TUNE_INNER)
      Serial.print(" | ");
#endif
#if USE_POT_TUNE_OUTER_PID && USE_PID_OUTER
      Serial.print("oKP="); Serial.print(okpr, 1); Serial.print(" oKI="); Serial.print(okir, 2); Serial.print(" oKD="); Serial.print(okdr, 1);
#endif
#if (USE_POT_TUNE_OUTER_PID && USE_PID_OUTER) && USE_POT_TUNE_INNER
      Serial.print(" | ");
#endif
#if USE_POT_TUNE_INNER
      Serial.print("KPh="); Serial.print(kph, 2); Serial.print(" KP="); Serial.print(kpb, 2); Serial.print(" KI="); Serial.print(ki_in, 2); Serial.print(" KD="); Serial.print(kd_in, 2);
#endif
      Serial.println();
    }
  }
#endif
#endif
}

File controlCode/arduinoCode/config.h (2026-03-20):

/*
 * Config / flags for arduinoCode.ino.
 * Include this file first so main code can branch on flags.
 */

#ifndef CONFIG_H
#define CONFIG_H

// Velocity scale and max used by LQR in normal mode (and available in any mode). Not from potentiometers.
#define VEL_SCALE  1.0f
#define VEL_MAX    8.55f
// Gain from wheel torque to velocity setpoint [rev/s per N·m] (used in control_helper for tau -> v).
#define K_TAU_TO_VEL  1.20f

// Inner loop velocity PID (v_des from LQR/IK, v_act from encoders); one set for all three motors.
#define INNER_VEL_KP    1.5f   // base KP (used at large errors, |e| > INNER_VEL_KP_E_LARGE)
#define INNER_VEL_KI    0.2f
#define INNER_VEL_KD    0.08f
#define INNER_VEL_I_MAX 5.0f
// When |velocity error| < this [rev/s], treat as zero (no P/I/D correction) so flat → zero command.
#define INNER_VEL_DEADBAND  0.05f

// Nonlinear KP: higher gain near zero error to punch through stiction; lower at large errors to avoid overshoot.
// KP ramps from INNER_VEL_KP_HIGH (at |e| <= E_SMALL) down to INNER_VEL_KP (at |e| >= E_LARGE).
#define INNER_VEL_KP_HIGH    16.0f   // aggressive gain for small errors (near stiction)
#define INNER_VEL_KP_E_SMALL 0.1f   // [rev/s] error below which full boost applies
#define INNER_VEL_KP_E_LARGE 0.8f   // [rev/s] error above which base KP applies
// Inner KP blends linearly from KP_HIGH to base KP between E_SMALL and E_LARGE (no curve).

// Orientation deadband [deg]: yaw only when OUTER_ANGLE_STICTION_HELP is 1; else roll, pitch, yaw.
#define ORIENTATION_DEADBAND_DEG  0.3f
// Outer LQR/PID: extra roll+pitch torque at small tilt errors (stiction chain), eases to 1.0. 1 = on (skips roll/pitch deadband, uses mult). 0 = old hard deadband on all axes.
#define OUTER_ANGLE_STICTION_HELP     1
#define OUTER_ANGLE_RAMP_SHAPE        0.35f   // 0 = linear mult blend between SMALL/LARGE deg; >0 = ease-out (power 1+shape, capped 8)
#define OUTER_ANGLE_BOOST_MAX_MULT    6.0f   // torque mult when max(|roll_err|,|pitch_err|) is tiny
#define OUTER_ANGLE_BLEND_SMALL_DEG   0.15f   // full BOOST_MAX_MULT below this error (deg)
#define OUTER_ANGLE_BLEND_LARGE_DEG   3.5f    // mult = 1.0 at/above this (deg)

// Loop rates [Hz]. Inner must be >= outer; inner runs encoder + velocity PI + motor command, outer runs IMU + LQR and updates v_des.
#define OUTER_LOOP_HZ  100
#define INNER_LOOP_HZ  200

// Orientation torque toggles (normal LQR / PID outer and pot-torque mode). 1 = use that axis; 0 = zero torque on that axis (platform does not balance that axis).
#define ENABLE_LQR_ROLL   1
#define ENABLE_LQR_PITCH  1
#define ENABLE_LQR_YAW    0

// 1 = outer loop uses PID on angle + rate error (same IK + velocity path as LQR). 0 = LQR.
// Ignored when USE_POT_MOTOR_VELOCITY or USE_POT_TORQUE is 1.
#define USE_PID_OUTER  1

// Outer-loop PID: tau_axis = Kp*e_angle + Ki*integral(e_angle) + Kd*e_rate [N·m before TAU_SCALE in control_helper].
// When OUTER_PID_SCALE_WITH_PLANT is 1, Kp/Ki/Kd are multiplied by (M*g*H_eff/J_axis) / ref so CoM height (H_CM),
// roll CoM offset (X_CM), mass M, and inertias match the LQR linearization (care_solve). Ref = nominal pitch plant.
// Tune per axis; at nominal plant (45 kg, 0.32 m, J=32) scale = 1 on roll/pitch.
#define OUTER_PID_SCALE_WITH_PLANT  1

#define OUTER_PID_KP_ROLL    75.0f
#define OUTER_PID_KI_ROLL    2.0f
#define OUTER_PID_KD_ROLL    28.0f
#define OUTER_PID_KP_PITCH  75.0f
#define OUTER_PID_KI_PITCH    2.0f
#define OUTER_PID_KD_PITCH   28.0f
#define OUTER_PID_KP_YAW     0.0f
#define OUTER_PID_KI_YAW     0.0f
#define OUTER_PID_KD_YAW     0.0f
// Anti-windup: clamp integrated angle error [rad·s] per axis.
#define OUTER_PID_INTEGRAL_CLAMP  0.4f
// Optional saturation of raw body torque before TAU_SCALE [N·m]; set large enough to not clip normal operation.
#define OUTER_PID_TAU_RAW_CLAMP   40.0f

// 1 = initialize and use second IMU (IMU B) on I2C 0x4B. 0 = skip IMU B; only IMU A required; control axis mirrors IMU A.
#define USE_IMU_B  0

// 1 = use only the sensor at 0x4B (BNO080): setup never touches 0x4A; platform (IMU A API) reads from that chip; control axis mirrors it.
// When this is 1, USE_IMU_B is ignored (single IMU on 0x4B; dual-IMU mode is off).
#define USE_IMU_B_AS_A  0

// 1 = print when IMU A stops returning new packets (getSensorEvent false) and when it recovers — use to diagnose frozen orientation.
#define DEBUG_IMU_A_NO_EVENT  0

// 1 = after sustained stall, call sensor_init() to reset I2C + IMU(s) (helps recover from I2C/sensor lockup without power cycle).
#define IMU_A_AUTO_RECOVER           0
#define IMU_A_STALL_RECOVER_AFTER_FAIL 500U   // consecutive failed reads before reinit (~1–2 s at outer-loop rate)
#define IMU_A_RECOVER_COOLDOWN_MS    3000U   // min time between recovery attempts

// 1 = potentiometers directly set velocity command to each motor (v1, v2, v3); LQR is not used.
// 0 = normal mode: LQR outer loop + motor velocity PI inner loop.
#define USE_POT_MOTOR_VELOCITY  0
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

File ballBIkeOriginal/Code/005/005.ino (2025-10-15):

#include <Arduino.h>
#include "ODriveCAN.h"

//PID
#include <PID_v1.h>

// PID1
double Pk1 = 2.5;   // 4.5
double Ik1 = 15;    // 12
double Dk1 = 0.07;  // 0.07

double Setpoint1, Input1, Output1, Output1a;    // PID variables
PID PID1(&Input1, &Output1, &Setpoint1, Pk1, Ik1 , Dk1, DIRECT);    // PID Setup

// CAN bus baudrate. Make sure this matches for every device on the bus
#define CAN_BAUDRATE 250000

// ODrive node_id for odrvives
#define ODRV0_NODE_ID 0
#define ODRV1_NODE_ID 1
#define ODRV2_NODE_ID 2
#define ODRV3_NODE_ID 3
#define ODRV4_NODE_ID 4

// Uncomment below the line that corresponds to your hardware.
// See also "Board-specific settings" to adapt the details for your hardware setup.

#define IS_TEENSY_BUILTIN // Teensy boards with built-in CAN interface (e.g. Teensy 4.1). See below to select which interface to use.
// #define IS_ARDUINO_BUILTIN // Arduino boards with built-in CAN interface (e.g. Arduino Uno R4 Minima)
// #define IS_MCP2515 // Any board with external MCP2515 based extension module. See below to configure the module.


/* Board-specific includes ---------------------------------------------------*/

#if defined(IS_TEENSY_BUILTIN) + defined(IS_ARDUINO_BUILTIN) + defined(IS_MCP2515) != 1
#warning "Select exactly one hardware option at the top of this file."

#if CAN_HOWMANY > 0 || CANFD_HOWMANY > 0
#define IS_ARDUINO_BUILTIN
#warning "guessing that this uses HardwareCAN"
#else
#error "cannot guess hardware version"
#endif

#endif

#ifdef IS_ARDUINO_BUILTIN
// See https://github.com/arduino/ArduinoCore-API/blob/master/api/HardwareCAN.h
// and https://github.com/arduino/ArduinoCore-renesas/tree/main/libraries/Arduino_CAN

#include <Arduino_CAN.h>
#include <ODriveHardwareCAN.hpp>
#endif // IS_ARDUINO_BUILTIN

#ifdef IS_MCP2515
// See https://github.com/sandeepmistry/arduino-CAN/
#include "MCP2515.h"
#include "ODriveMCPCAN.hpp"
#endif // IS_MCP2515

# ifdef IS_TEENSY_BUILTIN
// See https://github.com/tonton81/FlexCAN_T4
// clone https://github.com/tonton81/FlexCAN_T4.git into /src
#include <FlexCAN_T4.h>
#include "ODriveFlexCAN.hpp"
struct ODriveStatus; // hack to prevent teensy compile error
#endif // IS_TEENSY_BUILTIN

/* Board-specific settings ---------------------------------------------------*/

/* Teensy */

#ifdef IS_TEENSY_BUILTIN

FlexCAN_T4<CAN1, RX_SIZE_256, TX_SIZE_16> can_intf;

bool setupCan() {
  can_intf.begin();
  can_intf.setBaudRate(CAN_BAUDRATE);
  can_intf.setMaxMB(16);
  can_intf.enableFIFO();
  can_intf.enableFIFOInterrupt();
  can_intf.onReceive(onCanMessage);
  return true;
}

#endif // IS_TEENSY_BUILTIN

/* MCP2515-based extension modules -*/

#ifdef IS_MCP2515

MCP2515Class& can_intf = CAN;

// chip select pin used for the MCP2515
#define MCP2515_CS 10

// interrupt pin used for the MCP2515
// NOTE: not all Arduino pins are interruptable, check the documentation for your board!
#define MCP2515_INT 2

// freqeuncy of the crystal oscillator on the MCP2515 breakout board. 
// common values are: 16 MHz, 12 MHz, 8 MHz
#define MCP2515_CLK_HZ 8000000


static inline void receiveCallback(int packet_size) {
  if (packet_size > 8) {
    return; // not supported
  }
  CanMsg msg = {.id = (unsigned int)CAN.packetId(), .len = (uint8_t)packet_size};
  CAN.readBytes(msg.buffer, packet_size);
  onCanMessage(msg);
}

bool setupCan() {
  // configure and initialize the CAN bus interface
  CAN.setPins(MCP2515_CS, MCP2515_INT);
  CAN.setClockFrequency(MCP2515_CLK_HZ);
  if (!CAN.begin(CAN_BAUDRATE)) {
    return false;
  }

  CAN.onReceive(receiveCallback);
  return true;
}

#endif // IS_MCP2515


/* Arduinos with built-in CAN */

#ifdef IS_ARDUINO_BUILTIN

HardwareCAN& can_intf = CAN;

bool setupCan() {
  return can_intf.begin((CanBitRate)CAN_BAUDRATE);
}

#endif

// Instantiate ODrive objects
ODriveCAN odrv0(wrap_can_intf(can_intf), ODRV0_NODE_ID); // Standard CAN message ID
ODriveCAN odrv1(wrap_can_intf(can_intf), ODRV1_NODE_ID); // Standard CAN message ID
ODriveCAN odrv2(wrap_can_intf(can_intf), ODRV2_NODE_ID); // Standard CAN message ID
ODriveCAN odrv3(wrap_can_intf(can_intf), ODRV3_NODE_ID); // Standard CAN message ID
ODriveCAN odrv4(wrap_can_intf(can_intf), ODRV4_NODE_ID); // Standard CAN message ID
ODriveCAN* odrives[] = {&odrv0, &odrv1, &odrv2, &odrv3, &odrv4}; // Make sure all ODriveCAN instances are accounted for here

struct ODriveUserData {
  Heartbeat_msg_t last_heartbeat;
  bool received_heartbeat = false;
  Get_Encoder_Estimates_msg_t last_feedback;
  bool received_feedback = false;
};

// Keep some application-specific user data for every ODrive.
ODriveUserData odrv0_user_data;
ODriveUserData odrv1_user_data;
ODriveUserData odrv2_user_data;
ODriveUserData odrv3_user_data;
ODriveUserData odrv4_user_data;

// Called every time a Heartbeat message arrives from the ODrive
void onHeartbeat(Heartbeat_msg_t& msg, void* user_data_ptr) {
  ODriveUserData* odrv_user_data_ptr = static_cast<ODriveUserData*>(user_data_ptr);
  odrv_user_data_ptr->last_heartbeat = msg;
  odrv_user_data_ptr->received_heartbeat = true;
}

// Called every time a feedback message arrives from the ODrive
void onFeedback(Get_Encoder_Estimates_msg_t& msg, void* user_data_ptr) {
  ODriveUserData* odrv_user_data_ptr = static_cast<ODriveUserData*>(user_data_ptr);
  odrv_user_data_ptr->last_feedback = msg;
  odrv_user_data_ptr->received_feedback = true;
}

// Called for every message that arrives on the CAN bus
void onCanMessage(const CanMsg& msg) {
  for (auto odrive: odrives) {
    onReceive(msg, *odrive);
  }

}

// Uncomment below the line that corresponds to your hardware.
// See also "Board-specific settings" to adapt the details for your hardware setup.

#define IS_TEENSY_BUILTIN // Teensy boards with built-in CAN interface (e.g. Teensy 4.1). See below to select which interface to use.
// #define IS_ARDUINO_BUILTIN // Arduino boards with built-in CAN interface (e.g. Arduino Uno R4 Minima)
// #define IS_MCP2515 // Any board with external MCP2515 based extension module. See below to configure the module.

#include <Wire.h>

// #include <FastGPIO.h>
// #define APA102_USE_FAST_GPIO

#include <APA102.h>
// Define which pins to use.
const uint8_t dataPin = 2;
const uint8_t clockPin = 3;

// ** DEFINE VARIABLES **

int LED0;
int LED1;
int LED2;
int LED3;
int LED4;
int LED5;
int LED6;

float roll;
float rollTrim;
float rollTrimmed;

float fowardVel;
float fowardVelFiltered;

float rotVel;
float rotVelFiltered;

float wheel1;
float wheel2;
float wheel3;
float wheel4;
float wheel5;

int pot1;   // ctrl panel top pot
float pot2;   // ctrl panel bottom pot
float pot3;   // twist grip RH
float pot3Filtered;
float pot3FilteredConst;
float pot4;   // twist grip LH
float pot4Filtered;
float pot4FilteredConst;
int pot5;
int pot6;
int pot7;
int sw1;    // ctrl panel switch
int sw2;    // handlebar switch RH
int sw3;    // handlebar switch LH

int filterVar;
float leanToSteer;
float SteerToLean;

int clFlag;  // ODrive init flag
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

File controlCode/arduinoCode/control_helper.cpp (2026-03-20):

/*
 * Control helper: roll->motor1, pitch->motor2, yaw->motor3. Positive angle -> CW.
 * LQR + IK path: state from IMU A, reference from IMU B -> body torques -> wheel torques -> velocity.
 * When use_lqr_lookup: K is selected from control_lqr_lookup.h by H_eff = H_CM*cos(roll_ref)*cos(pitch_ref).
 */
#include "config.h"
#include "control_helper.h"
#include "control_lqr_lookup.h"
#include <Arduino.h>
#include <math.h>

// ----- LQR gain K (3x6): u = K @ (x - x_ref). Used when lookup disabled. -----
static const float K_LQR[3][6] = {
  { 343.068682f,  0.0f, 0.0f, 14.815250f, 0.0f, 0.0f },
  { 0.0f, 326.183053f, 0.0f, 0.0f, 14.760023f, 0.0f },
  { 0.0f, 0.0f, 31.622777f, 0.0f, 0.0f, 9.798879f },
};

// ----- IK: 3-wheel ball balancer (matches simulation/ik_validation/ik.py) -----
// alpha = 25.659 deg; wheels at 60°, 180°, 300°
static const float ALPHA_RAD = 25.659f * (PI / 180.0f);
static const float CA = cosf(ALPHA_RAD);
static const float SA = sinf(ALPHA_RAD);
static const float C1 = 0.5f;      // cos(60°)
static const float S1 = 0.866025f;  // sin(60°)
static const float C2 = -1.0f;      // cos(180°)
static const float S2 = 0.0f;
static const float C3 = 0.5f;       // cos(300°)
static const float S3 = -0.866025f; // sin(300°)
static const float IK_MAX_TORQUE = 2.0f;

// 0 = match Python/Simulink LQR->IK (pitch error -> pitch column of IK). 1 = swap roll/pitch before IK (old behavior).
#define LQR_REMAP_SWAP 0
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

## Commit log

2025-10-15 Initial commit: Add Omni-Directional Chair Project Plan
    [Ball.STEP, omni_wheel.STEP]
2025-10-17 Component Selection Document
    IMU
    Motor + Motor Calculations
    Batteries
    Controller
    Safety Considerations
2026-03-14 Control: LQR init K, roll/pitch-only swap, encoder in prints; serial monitor GUI
    - control_helper: LQR_PLANT_H_CM (avoid macro clash), compute K at init from Q/R, use K_computed when valid
    - control_helper.h: cstdint for uint8_t, control_computeKAtInit()
    - arduinoCode: SWAP_ROLL_PITCH (state/ref only; no M1/M2 swap), encoder e1,e2,e3 in printHeader/printRow, request encoder before each printRow
    - control_lqr_lookup.h: unsized first dimension for K_LQR_TABLE to fix toolchain init error
    - testScript/serial_monitor.py: GUI with per-signal checkboxes, current values panel, matplotlib plotter, encoder All/None; optional CSV log
    Made-with: Cursor
    [compare_sample.csv]
2026-03-14 Motor helper, MATLAB lookup, ik_validation lib restructure; ignore .vscode
    - .gitignore: add .vscode/
    - controlCode: remove old TwoIMUsandMotorControl sketches; motor_control_helper updates
    - simulation/Matlab: compute_lqr_lookup.m changes
    - simulation/ik_validation: move ik, lqr, physics_sim, pid, plant, remap, viz_3d into lib/; add platform_axes_viz.py; remove README/SIMULINK docs and deprecated scripts
    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
2026-03-14 Serial monitor and firmware: remove scale/max_vel, pot deadzone, record zeroing, motor_pos CSV, faster encoder rate
    - Arduino: drop scale/max_vel from printRow and header; add POT_DEADZONE and potNormalize() for zero deadzone; add SERIAL_PRINT_INTERVAL_MS (50ms) for 20Hz encoder/state output
    - Serial monitor: remove scale/max_vel from regex, parsing, groups, labels, CSV; zero motor positions (p1,p2,p3) when Record starts; save motor_pos.csv (time,p1,p2,p3) on Stop; display zeroed positio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
    - motor_control_helper: expose encoder positions (motor_getEncoderPositions) for serial/recording
    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
2026-03-17 Good code
    [compare_sample.csv, encoder.csv, vel_commands.csv]
